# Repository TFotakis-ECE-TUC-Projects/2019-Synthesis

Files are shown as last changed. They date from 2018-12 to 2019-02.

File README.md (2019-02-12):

# TUC Course: Analysis and Design (Synthesis) of Telecommunication Systems
## Project: Distributed Smoke Detection using Lasers

### Development Team Members
Andrianakis Manos
Fotakis Tzanis
Giannakopoulos Orestis
Kotridis Giorgos
Neonakis Paulos
Nichoritis Thanos
Ouroutzoglou Michail
Piskopos Dionisis
Polyzos Christos
Topalis Thanasis

### Professor Assistants
Giannelos Vaggelis
Vougioukas Giorgos

## Supervisor Professor
Bletsas Aggelos

# Introduction
---

## Semester Project Overview
The purpose of this project is to create a wireless sensor network in order to detect smoke in the TUC ECE's department building canteen and pinpoint its source.

### Main idea
Smoke has the ability to diffuse and absorb light, thus, by utilizing cheap sensors such as photodiodes, phototransistors or even photovoltaic panels, the impinging light’s intensity can be tracked and from its waveform in respect to time the existence of smoke can be inferred.
In order to cover a large amount of the available plane, lasers can be used in combination with mirrors as shown in Fig.1. By dividing the plane into cells/tables of 2 rows and 3 columns (see Fig.1), detection of smoke in a specific cell/table can be done by combining data from multiple sensors (e.g., row-1 and column-2 could detect smoke from table-2). 

### Project Structure
Work was split into 3 working groups, Hardware, Middleware and Software, in order to divide the workload among the project members. 
The system includes five sensor nodes (slaves, depicted in Fig.2-right), one base node (master, depicted in Fig.3) and one server PC (laptop, depicted in Fig.4). 
    • Slave: Controls laser diode, measures laser intensity and sends the measurement to the master node.
    • Master: Gives instructions to slave nodes so that they get synchronized to make the laser intensity measurements and to report them back on specific time slots. After the collection of all the measurements, a message to the server is sent with the collected data.
    • Server: Collects measured data, runs the detection algorithm on the collected data and updates the website.

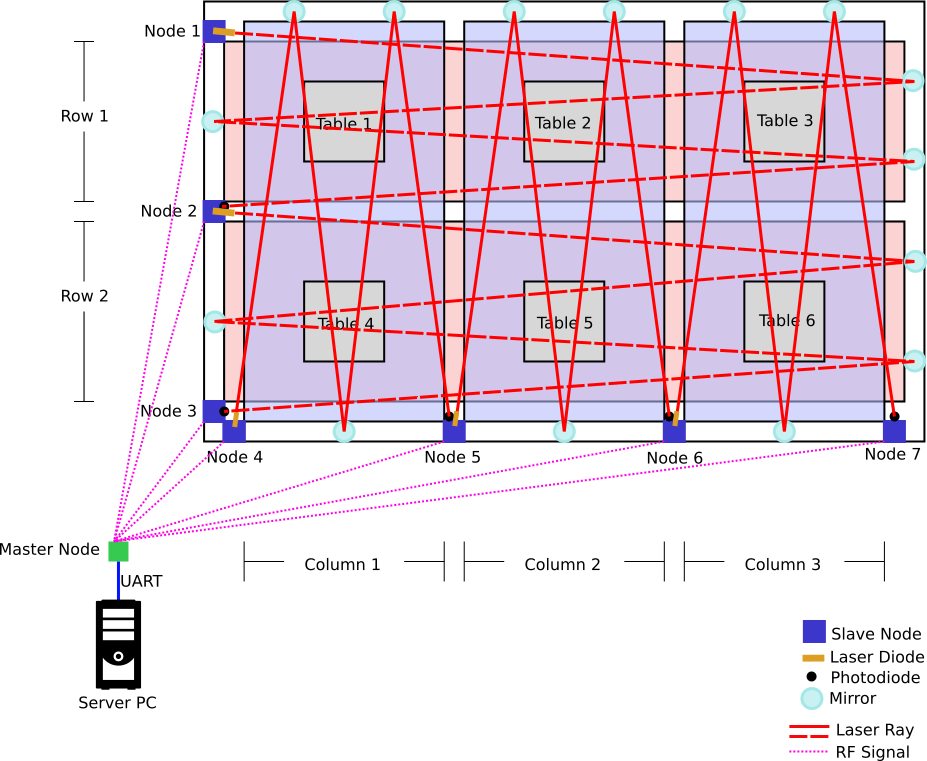
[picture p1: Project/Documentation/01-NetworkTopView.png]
Network Top View

Figure 1: Initial idea. Top view.

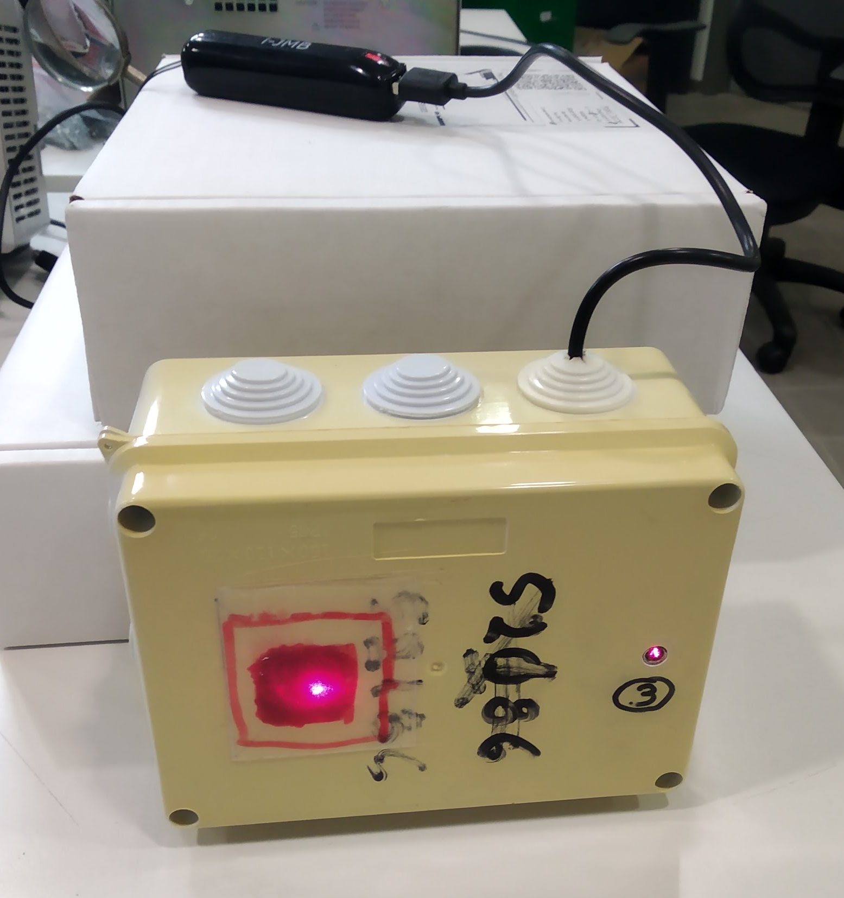
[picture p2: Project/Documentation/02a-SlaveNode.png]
Slave Node

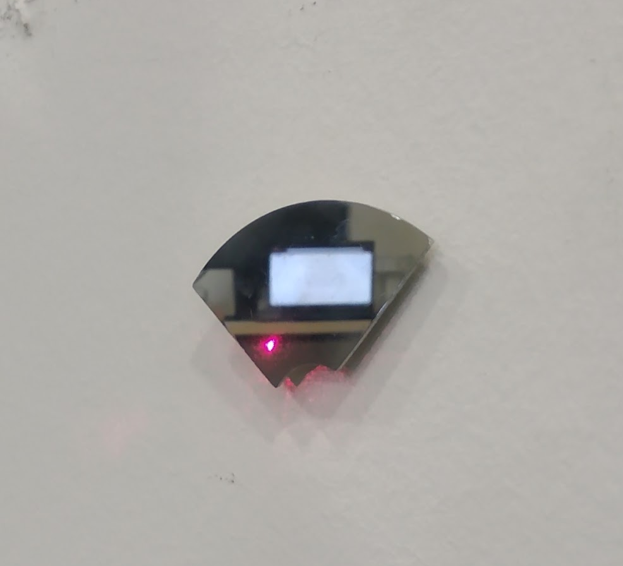
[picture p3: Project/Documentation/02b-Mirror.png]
Mirror

Figure 2: Slave Node on the left, mirror on the right.

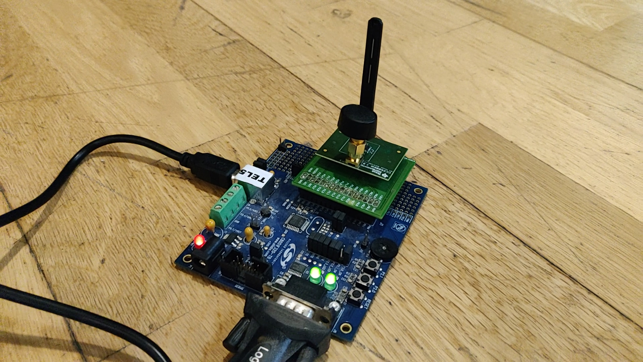
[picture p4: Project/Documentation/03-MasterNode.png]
Master Node

Figure 3: Master Node.

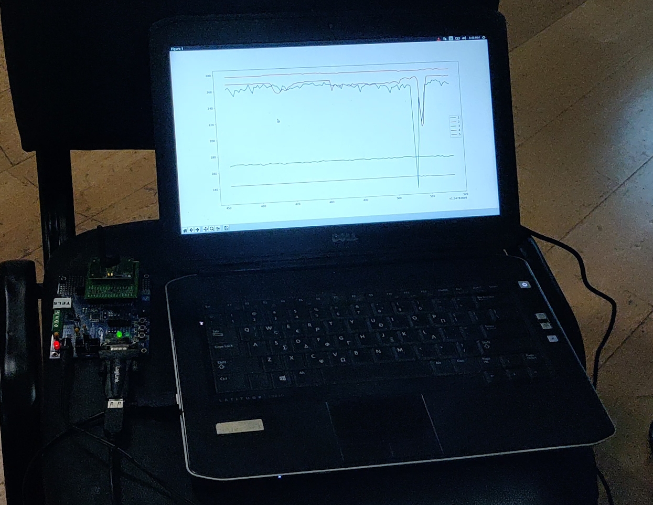
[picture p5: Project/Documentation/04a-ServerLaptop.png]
Server Laptop

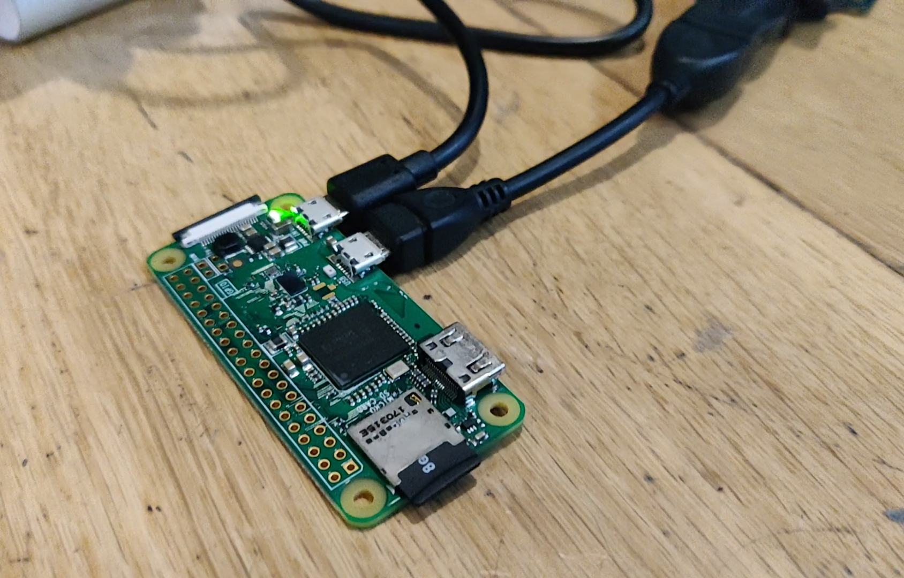
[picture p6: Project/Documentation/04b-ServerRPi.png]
Server RPi

Figure 4: Server on a laptop on the left, Server on a Raspberry Pi Zero W on the right.

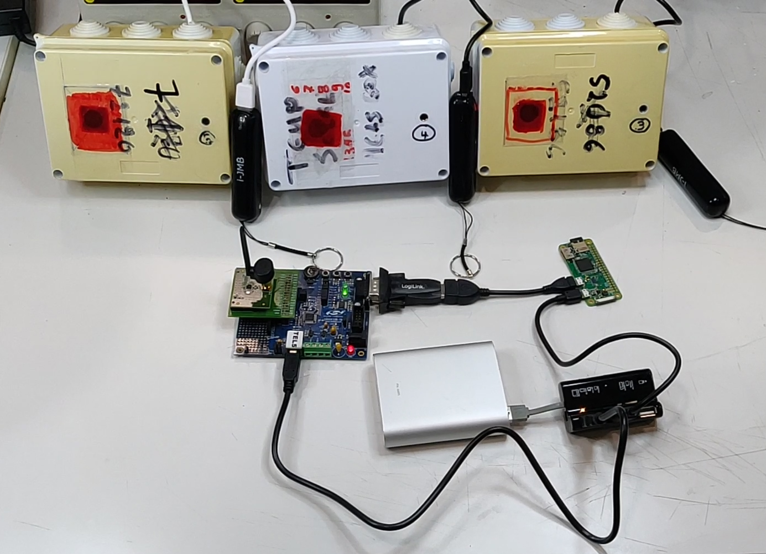
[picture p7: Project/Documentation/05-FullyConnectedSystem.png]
Fully Connected System

Figure 5: Fully connected System.

### Technical Difficulties
Due to environmental difficulties (walls prone to machinery vibrations, mounting issues, etc) that will be discussed below, time limitations became significant to the project’s overall development. As a result, the initial goal of detecting smoke on a grid was transformed into detecting smoke on a serial basis.

# Implementation
---

## Hardware

In this section we shall describe the analog part of our system. 

First of all, we shall analyze the basic hardware, as well as the installation components, that compose the system’s slave nodes.
Components:
    • Diode Laser (red)
    • Photovoltaic Panel
    • Power Supply
    • Mirror reflectors
    • Switching circuit
    • Optical filter
    • Control Unit & Radio
    • Case
    • Mounting Materials

### Diode Laser
For the purpose of our project, Diode Lasers (red) were the most power efficient and low cost. Additionally, red light has the biggest wavelength (compared with green and blue) thus, it is the least harmful for the human eye.

### Photovoltaic Panel
The photovoltaic panel is connected to the ADC (Analog to Digital Converter) of the Daughter Card in order to digitalize the signal.
Power Supply
The power supply was a major and very challenging problem we had to solve. Our first approach was to use conventional batteries. However, this approach did not provide a strictly constant DC voltage as long as the batteries were quickly discharged. So we had to make a regulator circuit to overcome this problem. Instead of this we used power banks, which were low cost, efficient, rechargeable and provided the desired DC constant power supply.
Mirror reflectors
Used to redirect the light beam to the desired destination.

### Switching Circuit

Laser Amplifier Circuit
Figure 6: Laser amplifier circuit.

This circuit was used for duty-cycle purposes, in the interest of minimizing the power consumption of the project. For the implementation of the switching circuit we used the following components:
    • 10 kΩ resistance
    • 2N3904 transistor
The switch circuit is represented in Fig. 6. In order to use the transistor as a switch circuit, we connected a 3,3 V output provided by the used target board via a resistance to the Base of the transistor, while connecting the output of the transistor (Collector) to the negative polarity of the diode laser. As a result, we manage a power consumption approximately to 100 mW for each laser circuit contained in a grid.

### Optical filter
In order to eliminate the ambient light’s intensity inside the slave’s case and only let the laser pass through, optical filters were used. An optical filter is a semi-transparent material that absorbs specific light wavelengths. The ones used in this project were filters that only allowed red pass through, which is the color of the used lasers. Such a filter could be purchased as a sheet of paper. However, for the purposes of this project and because of time shortage, several layers of red colored transparent tape were used in the place of the optical filter. Although, an optical filter cannot cut off the whole ambient light (ambient light also includes red wavelengths) and at the same time let the red laser pass through, it was a good enough solution, cutting off most of the other wavelengths.

### Control Unit & Radio
The slave node’s Control Unit & Radio is comprised of a Silicon Labs C8051F321 Daughter-Card, an 8-bit microcontroller mounted on a small development board with various IO ports (Buttons, IO pins, MicroUSB connector, etc), and a Silicon Labs CC2500 Radio Shield, which is an 8-bit microcontroller with radio modulation capabilities and I2C communication. It is responsible for collecting the needed measurements through its ADC (Analog to Digital Converter) component (see Middleware section), processing them and sending them to the master node and, also, switching its laser’s state for maintaining the system’s low power consumption characteristics.

### Case
Second handed Electrical Junction Boxes were used to accommodate all slave’s components. Two holes were drilled on its front face, one for holding the laser diode and one for letting the laser beam enter the box and hit the photovoltaic panel. The photovoltaic panel was placed as far from the hole as possible in order to eliminate the ambient light hitting it for reasons that will be discussed in the middleware section. For further elimination, the aforementioned optical filter was placed on top of that hole.

### Mounting Materials
Mounting hardware not only inside the slave’s case but also on the walls without establishing permanent installations (e.g. using holes and/or screws) that could damage the building, was a difficult, time and resource consuming task. Solutions such as 3D printed bases were tested in combination with materials such as Blu Tack and double sided tapes. Despite their light weight, stability problems surfaced. Therefore, the lasers' beams were diverted from the target. At last, the slaves cases were mounted on the walls using double sided tape and the reflection mirrors using only Blu Tack, which helped to easily redirect the laser beams.

### Slave Node Overview
Fig. 7 shows the wiring between the components we already discussed. Concerning the power supply of the circuit we used the daughter-card’s pins to provide power for both the circuit and the positive polarity of the laser diode. The daughter-card feeds the laser positive polarity and the switching circuit’s enable signal with VCC = 3.3V. Finally, the daughter-card’s power was provided by a 5V, 2600 mAh power bank which, in paper, could last for more than 18-hours of continuous use.
 
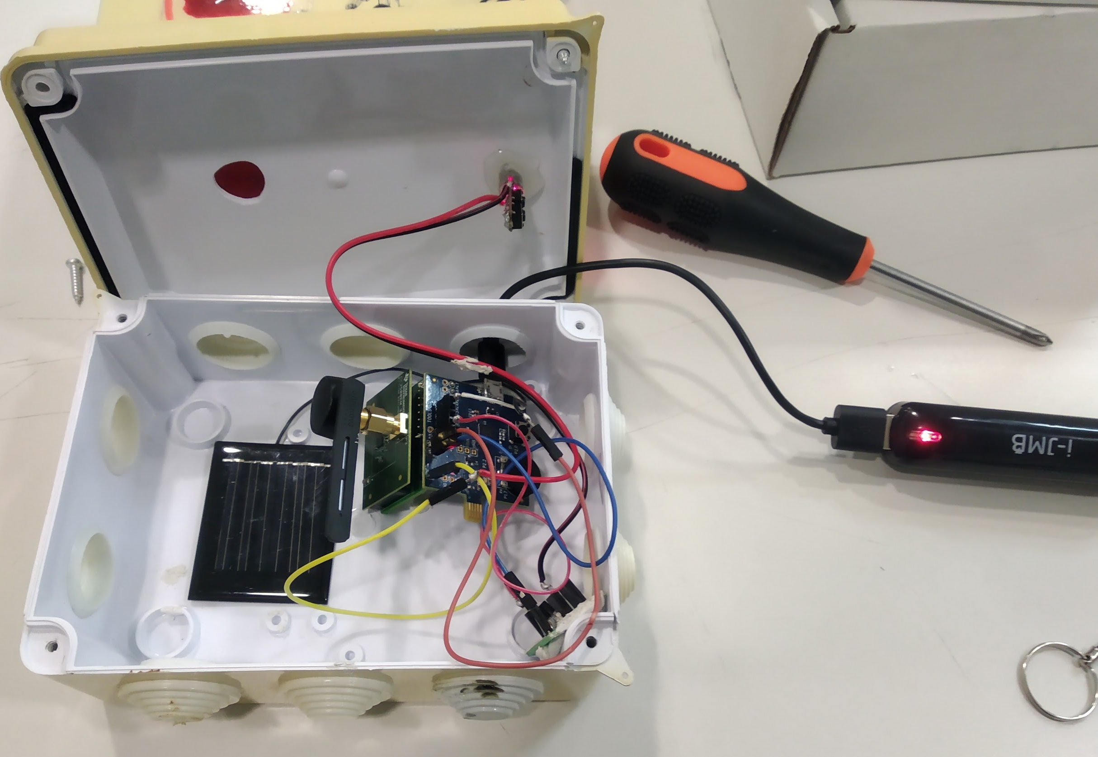
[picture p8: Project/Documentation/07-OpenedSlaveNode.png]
Opened Slave Node

Figure 7: Inside a slave’s casing.

### Master Node Overview
The base station/master node is comprised of a Silicon Labs C8051F320 DevKit, an 8-bit microcontroller mounted on a development board with various IO ports (Buttons, IO pins, DB9 connector, power supply connector, etc), a Silicon Labs CC2500 Radio Shield, an 8-bit microcontroller with radio modulation capabilities and I2C communication, a 5V power adapter and a Serial to USB adapter. The master node exchanges data with all slave nodes via the aforementioned radio shield. The collected data is then forwarded to the server via the DevKit’s serial port (utilizing its UART capabilities), which is then adapted to a USB port through the Serial to USB adapter. The latter is needed because, at the time of writing this report, the serial port is being deprecated and obsolete from every modern PC and also the Laptop/Raspberry Pi was used as a server.

## Middleware

### Connecting The Devices
The main objective was to collect the voltage values from each of the five slaves to the master node in order to forward them to the software to be processed for the detection. Achieving a reliable communication between one slave and the master was the first aim. Afterwards, the master node’s code was adjusted in order to control the rest.
The implementation began by writing code for the exchange of simple packets between the master and the slaves. RF-related registers were fine-tuned with the aid of the smartRF studio 7, which is an application that takes as input the desired design parameters and returns code that configures the nodes’ radios accordingly.
Every device can be used in one of the two available modes, receiver mode and transmitter mode, at a time. Checking for good communication between devices, one was set in transmitter mode and the other in receiver mode. As soon as they exchanged a single packet they would both switch modes and begin a new packet exchange. This process of exchanging packets would continue until a packet was lost. This method is called ping pong because a single packet is sent from one device to another and back again, like a ball of ping pong. 

### Handling the Data
After a reliable communication between devices has been established, the next step was to measure voltage values given from a power supply using the daughter-card’s analog-in pins and converting them into bytes, which will be later sent to the master. For this procedure an ADC (analog to digital converter) is required, an electronic component inside the slave’s microcontroller, which by comparing a port’s voltage to a set reference voltage, returns a measurement from 0 to 1023 of how close the port’s voltage is to the reference’s voltage. This method is called analog to digital conversion, because it accepts an analog, continuous signal and converts it into a discrete number referring to a specific moment of time. Following the addition of the appropriate functionality for the ADC part, the results of the converter were put in the tx Buffer (the buffer where the values that we want to be sent are into) in order to be transmitted to the master. After receiving the values from the slave, it was needed to view if the values from the power supply were sent correctly and in order to the master. Functionality extension had be made on the master, so that serial port communication capabilities could be used via the UART protocol. In order to view the received data from the PC, the Hercules application was used.

### Communication protocol
According to the initial plan, the master node was supposed to send a request to the first slave, waiting to receive a measurement, and then proceed to the next. After the implementation of this protocol, we came to the conclusion that this was not the ideal method as the whole procedure took around 2.5 seconds (500ms for each slave). This period was way too big for a smoke detection task, so a new, faster protocol had to be designed.
The final communication protocol expects the master to broadcast to all slaves an instruction to take a measurement. After the needed period of time for a measurement to be made (approximately 200ms), the master, starting from the first slave, sends a packet to request for that measurement and when received it continues to the next one, until it has collected all slaves’ measurements. That method was proved to be fast enough for our implementation as the elapsed time is being reduced to around 500ms.
Although, another issue occurred, as in unpredicted time, the communication ended suddenly, because a transmitted packet was lost. In this case, the procedure crashed as the master waited forever for a packet to be received. For that reason, a timeout routine was created which leads to a timeout after a short, pre defined period of time of 100ms, in order to avoid system crashes. When a timeout occurs, master continues its execution and requests the next node’s measurement. As a result, even in the case that a slave node is being lost from the network (e.g. battery fully discharged, change in environment leading to poor network connection, etc), the system’s execution will continue with no impact, except for always sending the last received measurement of the lost node.

### Measurements
To get a sense of the photovoltaic’s behaviour under the ambient light and the selected laser beam, measurements were made using one of the lab’s oscilloscope. Because most of the ambient light was generated from fluorescent lamps, which their operating principle is charging mercury to emit ultraviolet light to the tube’s gas, which it then emits visible light, a frequency of around 100 Hz was detected. Trying to remove that frequency, as well as, the ADC’s measurement noise, an average of 2048 measurements was computed, which was then sent to the master.
As soon as the first real world test took place at the desired area revealing the realistic measurements that had to be taken under consideration, a slight change in the measurement’s functionality had to be made in order to increase the sensitivity. The previous measurement method disadvantage was that it only measured ambient light’s intensity (which cannot be avoided) in combination with the laser’s intensity. However, the wanted measurement was (if possible) to measure only the laser’s intensity. So, to eliminate the ambient light’s intensity, it had to be measured and subtracted from the combination of ambient light and laser. The final measurement method works as follows: 
The laser is turned on, while the ADC takes 1024 measurements which are summed up to a variable, SUM, representing a measurement of the combination of the ambient light and the laser. Afterwards, the laser is turned off, while the ADC takes another 1024 measurements, which represent a measurement of the current ambient light. Those measurements are then subtracted from the SUM variable. Finally, the SUM is divided by 1024 to calculate the measurements’ arithmetic mean, which represent a close approximation of the laser’s intensity. To further eliminate ambient light’s intensity which caused the photovoltaic to operate on its nonlinear area, an optical filter, which only lets red (the laser’s color) to pass through, was used as discussed above.

### Master Node Algorithm Flow Chart
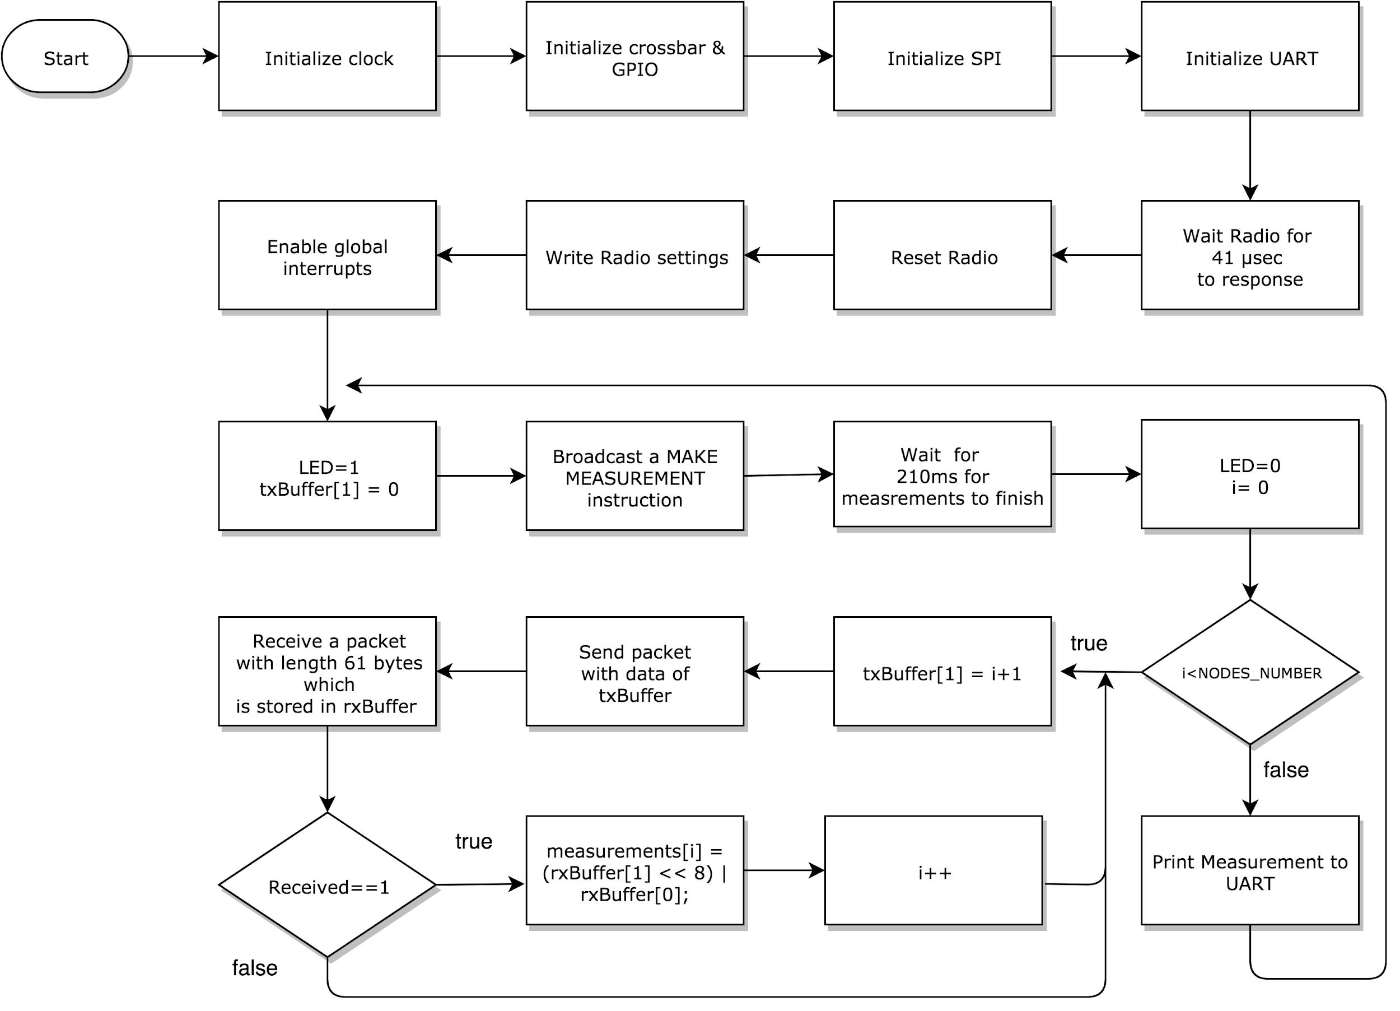
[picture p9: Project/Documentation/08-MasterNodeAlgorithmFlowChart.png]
Master Node Algorithm Flow Chart

Figure 8

### Slave Node Algorithm Flow Chart
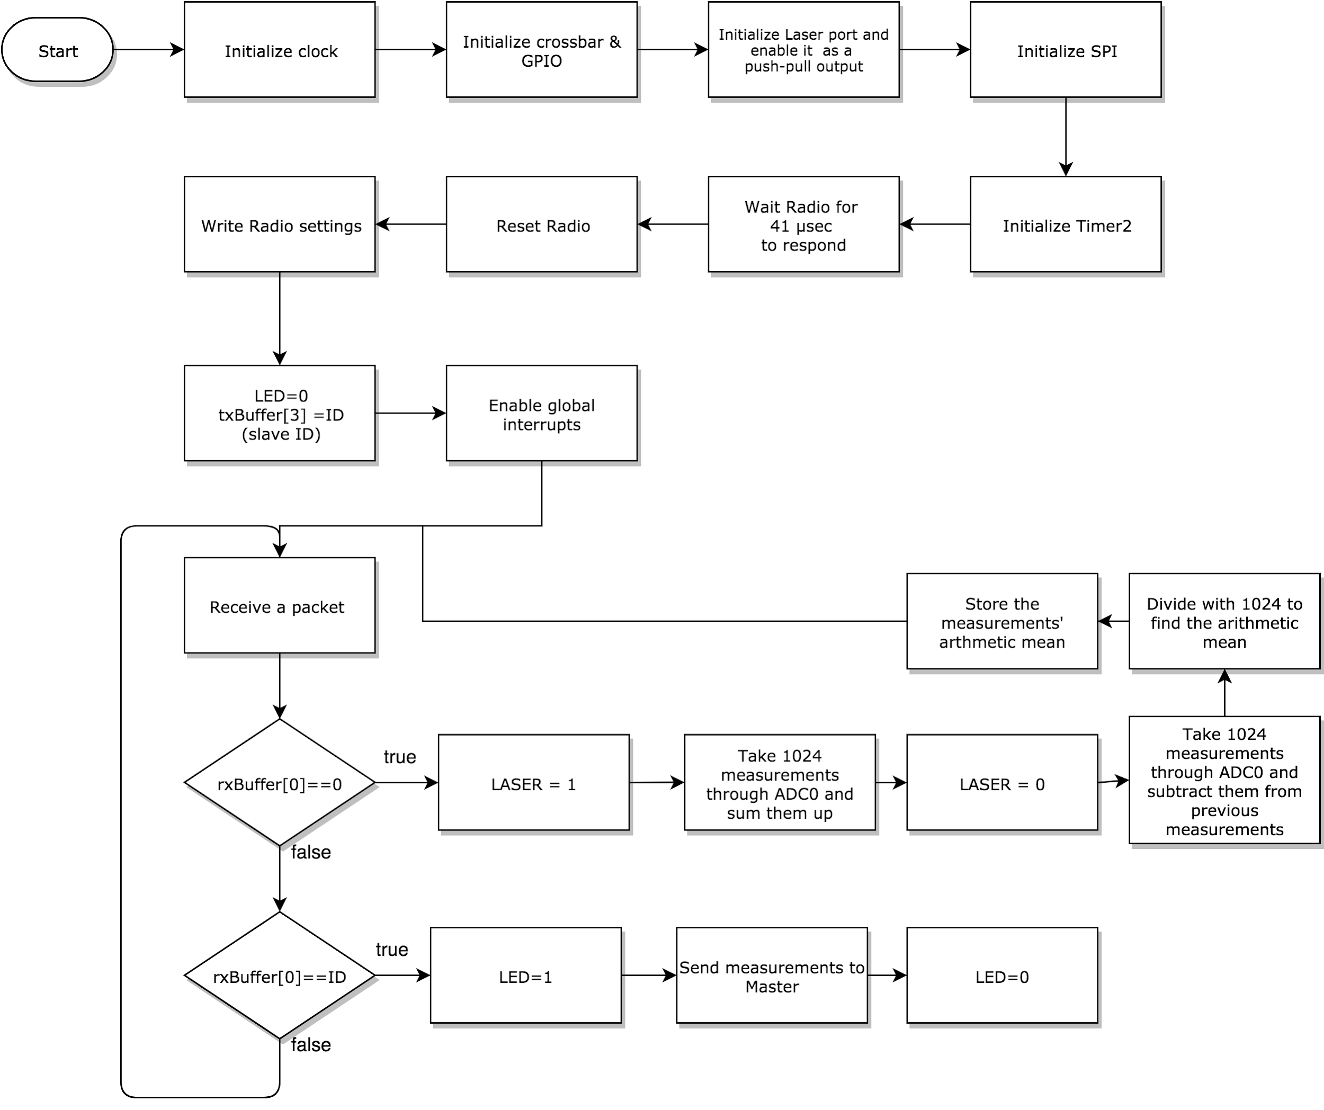
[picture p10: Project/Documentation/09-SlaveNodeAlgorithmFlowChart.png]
Slave Node Algorithm Flow Chart

Figure 9

## Software
The software team was responsible for fetching the data from the master node, keeping a log of them, and plotting them on MATLAB-like environment for the user to overwatch. In addition to that, accurate real-time detection of smoke is offered through simple digital signal processing, as well as the ability to project this information on a website, reachable from throughout the campus, alongside (un)pleasant sound effects as a notification/warning for the end user.

### Website & Data Handling
The website’s backend was created using the DJango framework, a high level web framework for rapid development, clean and pragmatic design. As it uses Python, it was the most suitable for the project’s needs because the smoke detection algorithm could be easily implemented inside the backend’s features. Last but not least, the data collection from the master node is done using the UART protocol through the PC’s serial port. 
On server launch, a new thread is created with the purpose of reading the serial port and storing its data into a FIFO buffer, from which the detection algorithm could make the needed calculations. Whenever a new calculation is ready, it is stored in a variable which can be sent to all the website’s connected clients. This thread also logs the received data, the timestamp of each measurement and the result of the detection. This can be quite useful since it allows the user to examine events in the past, even if the system is left unsupervised.
Another thread is also spawned in order to plot the received waveforms of each sensor on the screen.
The reason why separate threads are needed is because some of the aforementioned functionalities are blocking, meaning that the server would not continue its execution if single threaded.
The website’s frontend was created using plain HTML5 and CSS3 for the user interface as well as jQuery for dynamically updating the states of the predefined measured areas. In more detail, when the website is accessed, a periodic routine is triggered every 8 second to request from the server the current areas’ states. A json response is returned from the backend containing the needed data, which are stored in the previously mentioned variable. 
Whenever smoke is detected in an area, the corresponding area on the website turns from green to red and a sound effect is played, in order to catch the attention of the users.

### Observations On Data
Several factors were considered before deciding what is a good way to approach the detection. 
The ambient light introduced bias on the sensors. Normally this wouldn’t pose a problem, however considering the day/night cycle as well as the lights turning on/off, this was a problem. In addition to that, if the smoke settled in the room, the ambient light as well as the laser rays would be affected by a slow, time-dependant factor (e.g., day/night transition, smoke clearing out). These effects are different on each sensor considering their different location in the room and their electronic characteristics (e.g., panels are physically very different from each other).
The above observations are proof that the detection method needs to be able to adjust on its own, for each sensor, to a slow changing environment.
In contrast to the previous, instability on the part of the mirrors, due to vibrations etc., coupled with the thermal noise of the ADC, flickering can be noticed on the measurements. This small fluctuation needs to be filtered out and not be considered in the detection as it can potentially cause false positives.
Thus, it is now clear that the constant (or very slow), and fast components of the received waveforms must be discarded.

### DSP & Detection
Having said that, the digital signal processing part is now a lot more straightforward. By performing Discrete Time Fourier Transform (DTFT) on small time frames of the received waveforms, frequencies (such as the above) can be cropped in order to detect smoke from the rest of the signal. When there is no smoke, the intermediate frequencies (higher than 0 less than 1, see Fig. 11 left) offer small contribution to the overall signal. However, when smoke passes through the laser ray, a sudden drop at the sensor level occurs (also see in Fig. 11 right, how the intermediate frequencies get significant amplitude). A heuristic metric was developed by calculating the arithmetic mean of the absolute value of the intermediate frequencies. Through trial and error, a heuristic threshold value was identified and used as a means of checking whether there is smoke or not. Surprisingly, this method works quite good, all things considered.

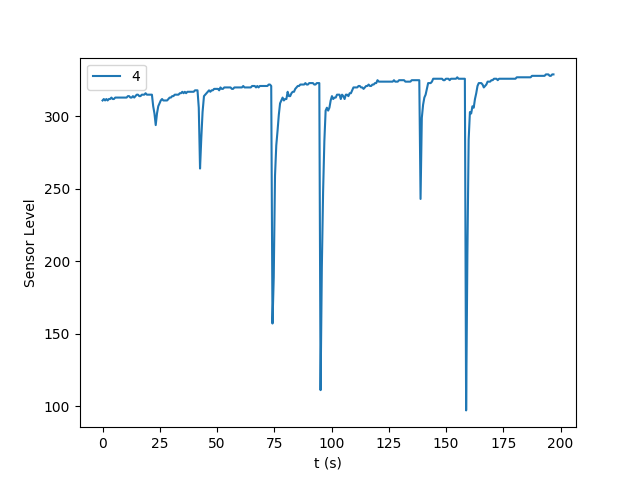
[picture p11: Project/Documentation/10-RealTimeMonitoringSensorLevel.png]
Real Time Monitoring Sensor Level

Figure 10: Real-time monitoring of Sensor Level.

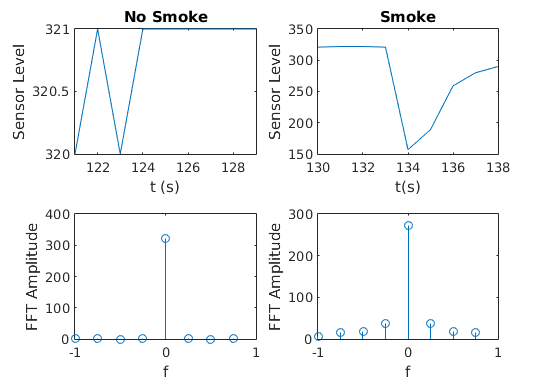
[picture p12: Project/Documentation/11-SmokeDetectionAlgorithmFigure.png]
Smoke Detection Algorithm Figure

Figure 11: The top figures are time windows without and with smoke. The bottom figures are their corresponding FFT waveforms. 

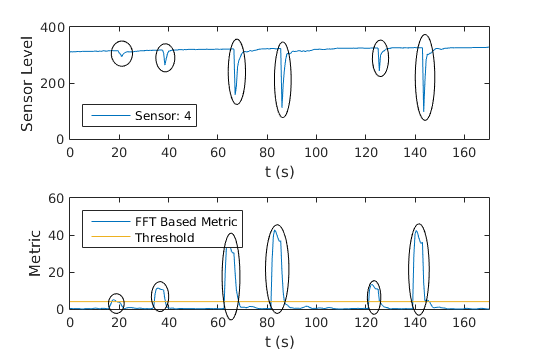
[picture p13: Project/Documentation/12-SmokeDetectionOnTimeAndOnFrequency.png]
Smoke Detection On Time And On Frequency

Figure 12: Waveform of sensor level (top), alongside the FFT based metric compared to the heuristic threshold (bottom). 

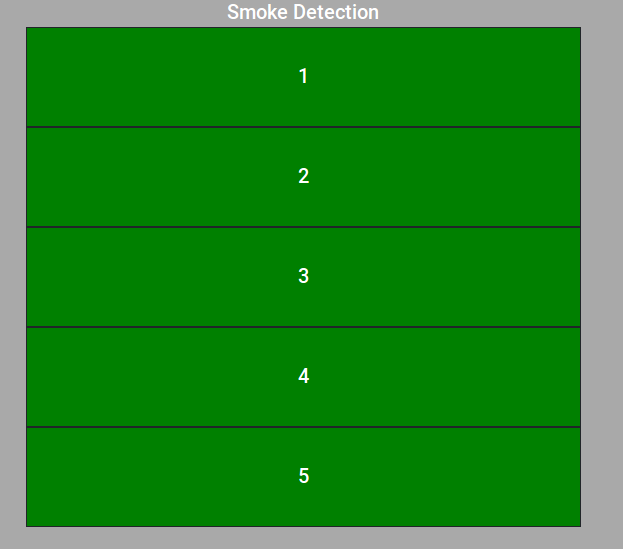
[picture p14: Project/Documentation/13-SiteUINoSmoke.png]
Site UI No Smoke

Figure 13: Website view without smoke.

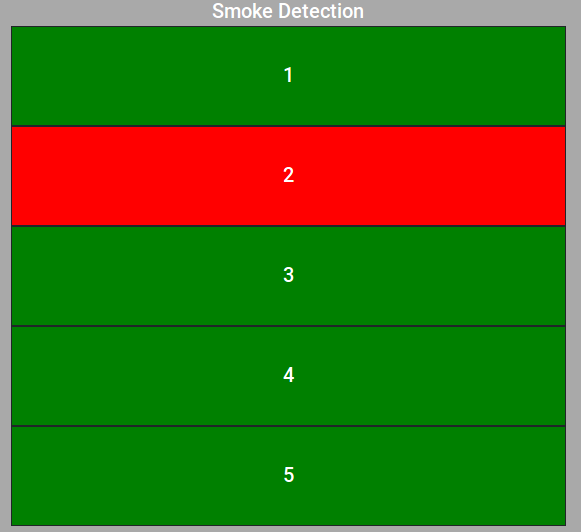
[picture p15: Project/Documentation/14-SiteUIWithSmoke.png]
Site UI With Smoke

Figure 14: Website view with smoke.

# Future Work
---
## Hardware
Low cost laser modules come with low quality, poor focus performance and endurance. In addition, generic mirrors affects laser beams’ focus and intensity over multiple reflections. Overall, the received beam on the photovoltaic panel loses its property of being a “beam” as it is getting distorted after all the needed reflections and its initial low focus. Optimizing the laser’s wavelength by selecting the one that gets the greatest absorption from gases that need to be detected, even other than smoke or even invisible to the human eye such as CO or dangerous flammable gases. Furthermore, optimized optical filters, better mounting solutions and smaller casing could improve sensitivity and ease of installation. 

## Middleware
Power consumption can be reduced using the minimum required  power output of transmitter in order to meet the requirements of  sensitivity of receiver for a successful communication. Also, lower data rate could lead to power efficiency.

## Software
Due to time constraints, the detection had to be performed in a simple straightforward way. The result is that we came up with a heuristic metric and a heuristic threshold that may require fine-tuning overtime. In the future, neural networks could be facilitated in order to make the system smarter and enabling it to pinpoint the exact location of the smoke, by comparing values of multiple (with possibly intersecting rays) sensors. Another benefit of this approach would be that we can drop the heuristic metrics and thresholds, thus making the detector much more robust and independent (in terms of fine-tuning).

# Links
---
Youtube Demo Video: https://youtu.be/7rDN7ZuSLMw
GitHub Repository: https://github.com/TFotakis/TUC-Synthesis

# The Team
---
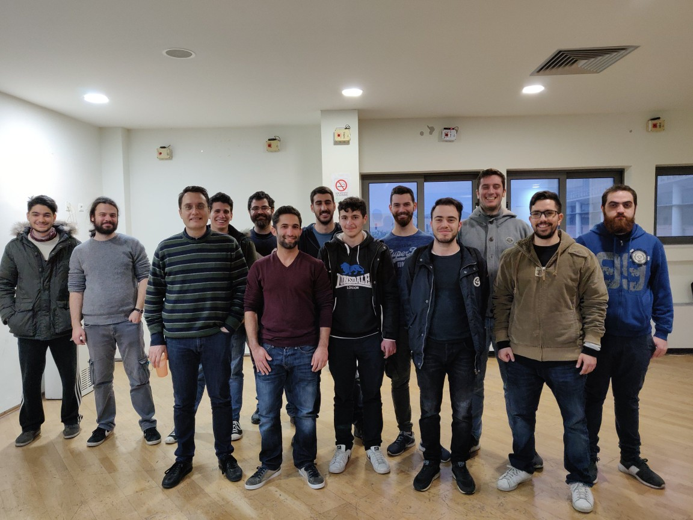
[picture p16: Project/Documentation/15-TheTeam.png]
The Team


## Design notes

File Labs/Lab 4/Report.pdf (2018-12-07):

# Ανάλυση και Σχεδίαση Τηλεπικοινωνιακών Διατάξεων

### Αναφορά Εργαστηρίου 4 Φωτάκης Τζανής - 2014030054

Σε συνεργασία με Πίσκοπο Διονύση

## Βρείτε τον ρυθμό bits per second (bps) του ADC και τον ρυθμό

bps του UART. Χάνονται δεδομένα? Εξηγήστε συνοπτικά.

Εξετάζοντας τον δοσμένο κώδικα, γίνονται αποδεκτά τα παρακάτω:
- Το UART είναι ρυθμισμένο σε 115200 Baudrate, δηλαδή έχει την ικανότητα να μεταδίδει από τον μικροελεγκτή προς την σειριακή θύρα με ρυθμό RATEUART=115200 bits per second των οποίων μέρος είναι η χρήσιμη πληροφορία (μέτρηση ADC) και ένα άλλο μέρος είναι πληροφορία του πακεταρίσματος του μηνύματος.
- Ο ADC ξεκινάει ένα conversion κάθε 100μs που σημαίνει ότι κάθε 100μs δίνεται στο σύστημα ένα interrupt για το γεγονός ότι υπάρχει μία έτοιμη τιμή από τον ADC.
- Δημιουργείται ένας μέσος όρος των μετρήσεων του ADC με πλήθος 2048 μετρήσεις και αμέσως μετά το αποτέλεσμα του μέσου όρου αποστέλλεται στο UART.
- Ο ADC δίδει ακρίβεια 10bit, δηλαδή μπορεί να αναγνωρίσει 1024 διαφορετικές στάθμες τάσης, άρα θα πρέπει να μεταδοθεί μήνυμα 10bit μέσω του UART.
Σύμφωνα με τα παραπάνω προκύπτει ότι:
RATE | 8.82 bits per second ADC =

10bit
2048 conversions * 100 10 sec

−6 = 4

Άρα επειδή RATEADC << RATEUART μπορούμε να είμαστε σίγουροι ότι δεν χάνονται δεδομένα από τον ADC προς την σειριακή θύρα.

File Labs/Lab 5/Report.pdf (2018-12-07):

# Ανάλυση και Σχεδίαση Τηλεπικοινωνιακών Διατάξεων

Αναφορά Εργαστηρίου 5
Πίσκοπος Διονύσης - 2015030115 Φωτάκης Τζανής - 2014030054

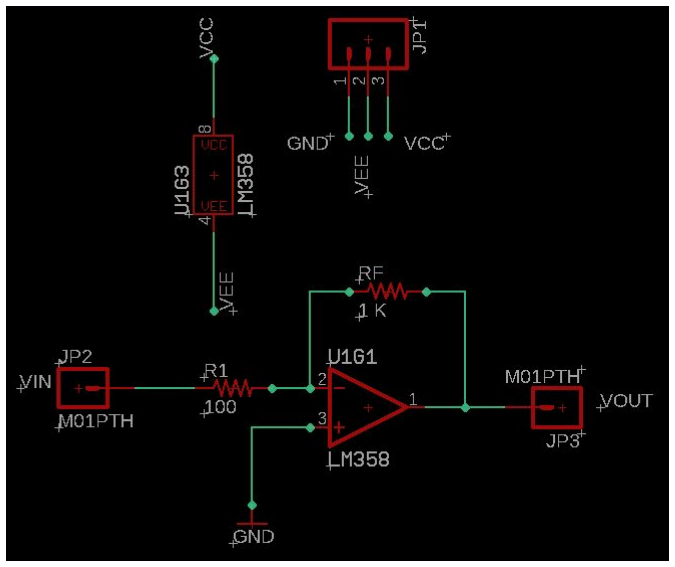
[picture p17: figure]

OpAmp Schematic

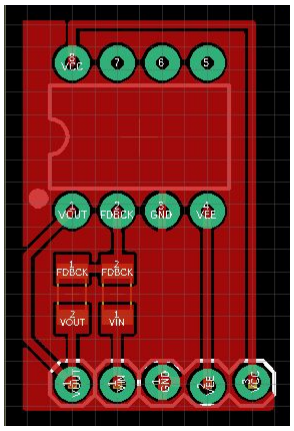
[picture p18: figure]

OpAmp Layout

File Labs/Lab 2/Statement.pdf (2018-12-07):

Πολυτεχνείο Κρήτης
Τμήμα Ηλεκτρονικών Μηχ\κών & Μηχ\κών Η\Υ

### Χειμερινό Εξάμηνο 2010-2011

# ΤΗΛ 412 Ανάλυση και Σχεδίαση (Σύνθεση)

## Τηλεπικοινωνιακών Διατάξεων

7

ου Εξαμήνου

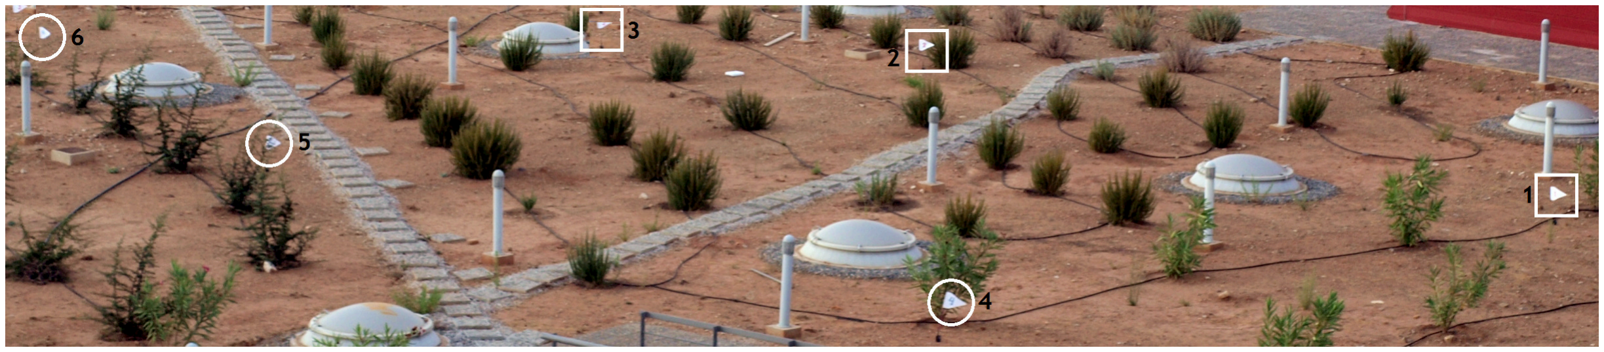
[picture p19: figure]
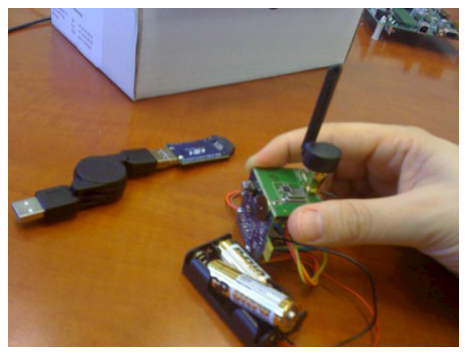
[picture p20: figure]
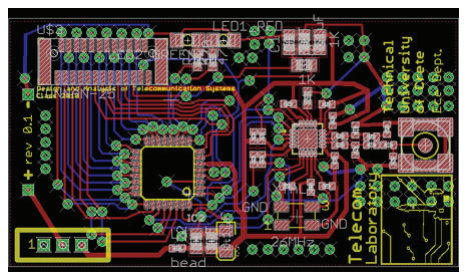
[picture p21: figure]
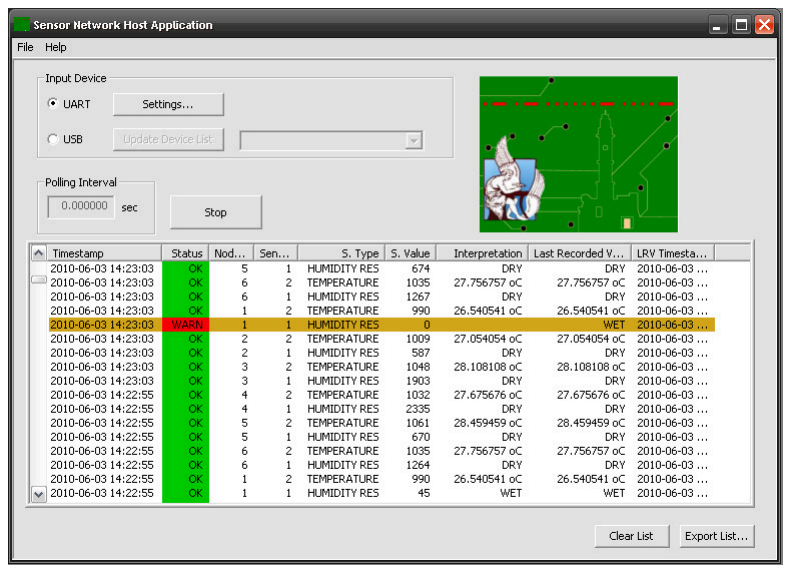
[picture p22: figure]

## Σειριακή Επικοινωνία Υπολογιστή με Πλακέτα

## Ανάπτυξης

Υποστηρικτικό Υλικό
Διδάσκων: ΄Αγγελος Μπλέτσας aggelos@telecom.tuc.gr

### version 0.1.0

1 | Εισαγωγή
1.1 | Σειριακή Διεπαφή (J5)

Η πλακέτα ανάπτυξης C8051F320 που χρησιμοποιείται στα πλαίσια του εργαστηρίου του μαθήματος, είναι εξοπλισμένη με ένα RS-232 κύκλωμα πομποδέκτη καθώς και ένα DB-9 connector.
Τα παραπάνω μπορούν να χρησιμοποιηθούν, με σκοπό την καλύτερη αποσφαλμάτωση και τον έλεγχο ορθής λειτουργίας των συστημάτων που υλοποιούμε μέσω της εκτύπωσης στην οθόνη μηνυμάτων ή τιμών μεταβλητών.
Για χάριν της καλύτερης εξοικείωσης σας με την δημιουργία σειριακής επικοινωνίας μεταξύ του υπολογιστή και της πλακέτας ανάπτυξης σας δίνεται το project με όνομα UART EXAMPLE το οποίο βρίσκεται στον φάκελο με τον κωδικό του μαθήματος στον υπολογιστή του κάθε πάγκου του εργαστηρίου. Για την επεξεργασία του κώδικα θα χρησιμοποιηθεί η πλατφόρμα της Sillabs Επιπλέον σας δίνεται το header file C8051F320.h που περιέχει ορισμούς σταθερών παραμέτρων του μικροελεγκτή μας.
Για την επεξεργασία των κωδίκων και την φόρτωση τους στον μικροελεγκτή θα χρησιμοποιηθεί η πλατφόρμα της Silabs ενώ σαν τερματικό θα χρησιμοποιηθεί το Hercules, μία standalone εφαρμογή, το εκτελέσιμο αρχείο της οποίας είναι επίσης τοποθετημένο στον φάκελο με τον κωδικό του μαθήματος.

2 | Εφαρμογή Hercules
2.1 | Εγκατάσταση και Λειτουργία

΄Οπως αναφέραμε παραπάνω το εκτελέσιμο αρχείο της εφαρμογής Hercules είναι τοποθετημένο στον φάκελο με όνομα τον κωδικό του μαθήματος.
Αφότου εκκινήσετε την εφαρμογή, θα σας εμφανιστεί ένα παράθυρο όπως αυτό απεικονίζεται στο Σχήμα 1.

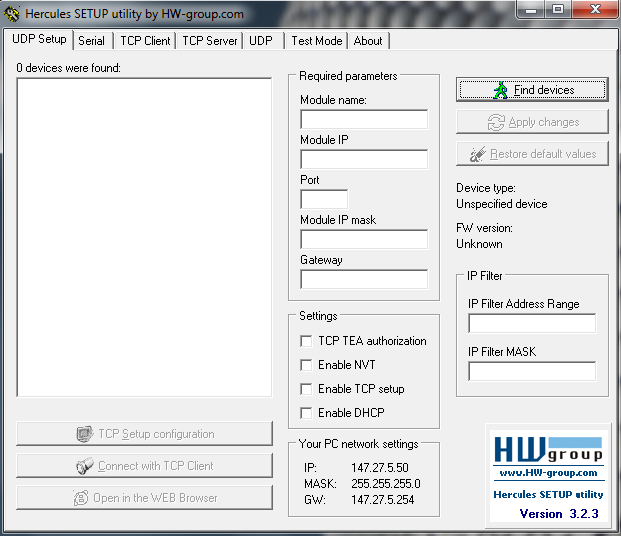
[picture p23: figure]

Σχήμα 1: Εκκίνηση τερματικού παραθύρου της εφαρμογής Hercules.

Στην συνέχεια επιλέγοντας την καρτέλα Serial καλείστε να ρυθμίσετε κάποιες παραμέτρους στο δεξί μέρος του παραθύρου, όπως αυτό της σειριακής θύρας (π.χ. COM1 ).

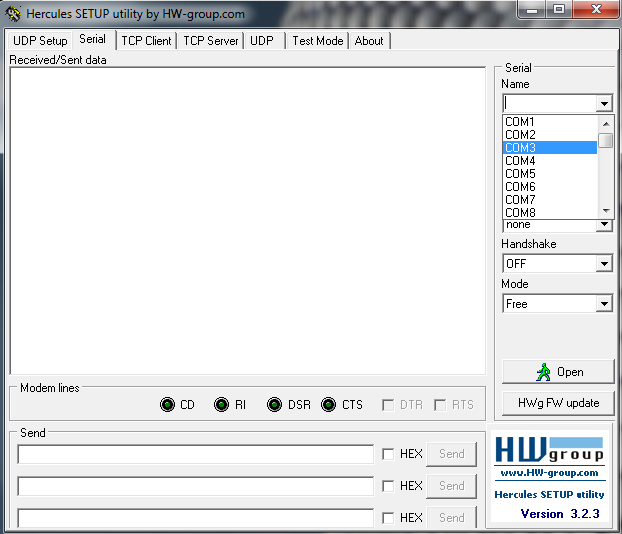
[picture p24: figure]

Σχήμα 2: Εφαρμογή Hercules (συνέχεια).

΄Ετσι για την ορθή ρύθμιση των παραμέτρων, χρειάζεται αφού πρώτα συνδέσετε τον Serial to USB μετατροπέα στην αντίστοιχη θύρα, να μεταβείτε στον Device Manager του υπολογιστή σας. Στην καρτέλα για τις σειριακές θύρες (Ports (COM & LPT)) αφού δείτε τον αριθμό της εικονικής σειρι-

ακής θύρας που δημιουργήθηκε, τον επιλέγετε στην αντίστοιχη καρτέλα της εφαρμογής Hercules.

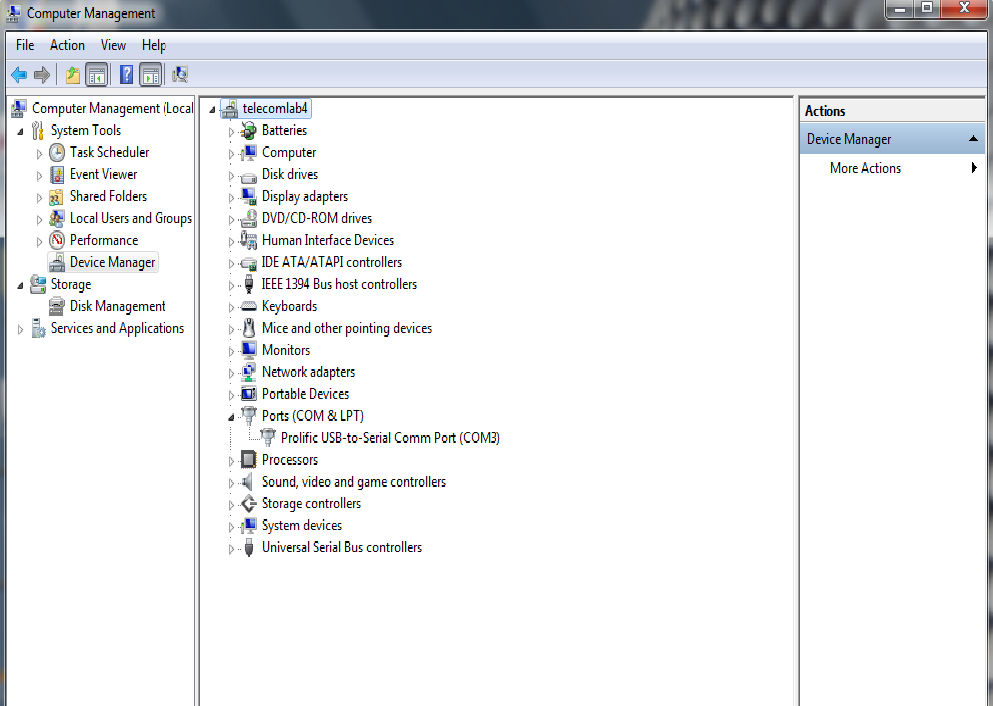
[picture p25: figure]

Σχήμα 3: Ρύθμιση παραμέτρων στην εφαρμογή Hercules.

΄Επειτα, σας δίνεται η δυνατότητα να επιλέξετε διαφορετική τιμή για το Baud Rate κάτι το οποίο δεν πρέπει να ξεχάσετε να δηλώσετε σαν σταθερά στον κώδικα σας. Η default τιμή του είναι 9600 και είναι αυτή που χρησιμοποιείται στο παράδειγμα το οποίο θα εξασκηθείτε.
Τέλος με το κουμπί open η σειριακή θύρα θα ‘ανοίξει’ και θα είναι έτοιμη για την λήψη δεδομένων από την πλακέτα ανάπτυξης.

## 3 Περιγραφή Δοθέντος Λογισμικού

Στο παράδειγμα που σας δίνεται, μπορείτε να εισάγετε κάποιο χαρακτήρα και το τερματικό θα εκτυπώσει την είσοδο σας από το πληκτρολόγιο σε δεκαεξαδική μορφή.
΄Ενα παράδειγμα υλοποιήσης εμφανίζεται στο Σχήμα 4.

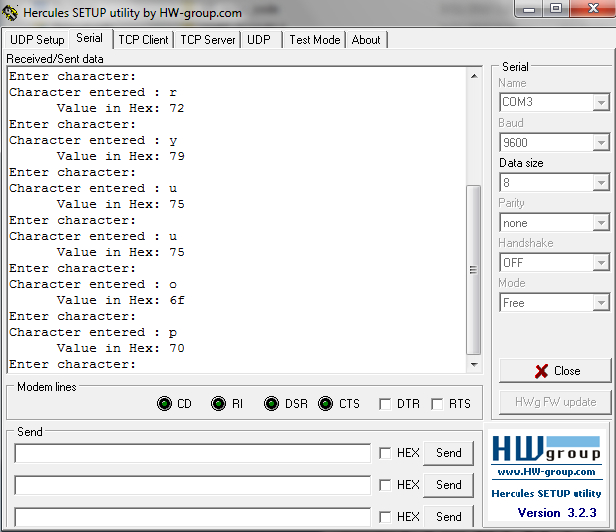
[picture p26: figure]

Σχήμα 4: Παράδειγμα F32x UART STDIO.c στην εφαρμογή Hercules.

## 3.1 Κώδικας F32x UART STDIO.c

Ορισμός των header files που περιέχουν απαραίτητες δηλώσεις καταχωρητών καθώς και συναρτήσεων απαραίτητων για διάβασμα από το πληκτρολόγιο και εκτύπωση στην οθόνη.

#include <c8051f320.h> | // SFR declarations

#include <stdio.h>

#include <common.h>

Στην συνέχεια ορίζονται 2 σταθερές όπως η συχνότητα του εσωτερικού ταλαντωτή η οποία τίθεται στα 12MHz ενώ ο ρυθμός μεταφοράς δεδομένων στην σειριακή επικοινωνία ορίζεται στα
9600bps.
#define SYSCLK | 12000000 | // SYSCLK frequency in Hz

#define BAUDRATE | 9600 | // Baud rate of UART in bps

Ακόμη ορίζεται ένας buffer με το όνομα myData τύπου BYTE ο οποίος θα αποθηκευτεί σ΄ ένα άλλο κομμάτι της μνήμης (xdata) για το οποίο έχει γίνει εκτενής περιγραφή στην αναφορά

του προηγούμενου εργαστηρίου.

BYTE xdata myData[]= {20, 0, 1, 2, 3, 4, 5, 6, 7, 8, 9, 10, 11, 12, 13, 14};

Ορισμός των πρωτοτύπων των συναρτήσεων που μερικές από τις οποίες θα χρησιμοποιηθούν
στο παρακάτω πρόγραμμα (UART0 Init, SYSCLK Init, PORT Init).

void SYSCLK_Init (void);
void UART0_Init (void);
void PORT_Init (void);
void Timer2_Init (int);

Στην κύρια συνάρτηση του προγράμματος μας αφού πρώτα ορίσουμε μια μεταβλητή τύπου χαρακτήρα, απενεργοποιήσουμε τον watchdog timer και καλέσουμε τις 3 απαραίτητες συναρτήσεις για την αρχικοποίηση των Ports, του εσωτερικού ταλαντωτή και της σειριακής επικοινωνίας αντίστοιχα, καλούμε την συνάρτηση printf με ορίσματα τις προτάσεις που θέλουν να εκτυπωθούν στην οθόνη. Να επισημάνουμε ακόμη ότι η συνάρτηση getChar() χρησιμοποιείται για το διάβασμα

χαρακτήρων από το πληκτρολόγιο.

void main (void)
{
unsigned char inputcharacter;
int byteAsInt;
int iter;
PCA0MD &= ~0x40; | // WDTE = 0 (clear watchdog timer
| // enable)
PORT_Init(); | // Initialize Port I/O
SYSCLK_Init (); | // Initialize Oscillator
UART0_Init();
while (1)
{
printf ("\nEnter character: ");
inputcharacter = getkey ();
printf("\nCharacter entered : %c",inputcharacter);
printf("\n | Value in Hex: %bx",inputcharacter);
printf("\n");
printf("Buffer myData:");
for (iter=1;iter<=(sizeof(myData)-1);iter++){ byteAsInt=myData[iter];
printf("%d ",byteAsInt);
}//end of for
printf("\n");
}
}

΄Ετσι καλούμαστε να εισάγουμε σαν είσοδο κάποιο χαρακτήρα και το πρόγραμμα μας θα εκτυπώσει την τιμή του χαρακτήρα σε δεκαεξαδική μορφή.

Επιπροσθέτως, ένας βρόγχος επανάληψης for υλοποιείται, με σκοπό την εκτύπωση στο τερματικό των στοιχείων του buffer που ορίστηκε παραπάνω.
Παρακάτω ακολουθούν οι κώδικες των συναρτήσεων που καλούνται κατά την διάρκεια του προγράμματος.
Αρχικά με την κλήση της PORT Init θα ενεργοποιήσουμε το P0.4 ως push-pull ψηφιακή έξοδο
και το P0.5 ως open-drain.

void PORT_Init (void)
{
P0MDOUT |= 0x10; | // enable UTX as push-pull output
XBR0 | = 0x01; | // Enable UART on P0.4(TX) and P0.5(RX)
XBR1 | = 0x40; | // Enable crossbar and weak pull-ups
}

Την συνάρτηση SYSCLK Init την έχετε επίσης συναντήσει σε προηγούμενα εργαστήρια και χρησιμοποιείται για να καθορίσουμε ως ρολόι του συστήματος τον εσωτερικό ταλαντωτή.

void SYSCLK_Init (void)
{
OSCICN |= 0x03; | // Configure internal oscillator for
// its maximum frequency
CLKSEL = 0x20;
RSTSRC | = 0x04; | // Enable missing clock detector

}

Τέλος η συνάρτηση UART0 Init χρησιμοποιείται για την εγκαθίδρυση σειριακής επικοινωνίας ανάμεσα στον υπολογιστή και στην πλακέτα ανάπτυξης με ρυθμό μεταφοράς που ορίζεται στις πρώτες γραμμές του προγράμματος.

void UART0_Init (void)
{
SCON0 = 0x10; | // SCON0: 8-bit variable bit rate
// | level of STOP bit is ignored
// | RX enabled
// | ninth bits are zeros
// | clear RI0 and TI0 bits
if (SYSCLK/BAUDRATE/2/256 < 1) {
TH1 = -(SYSCLK/BAUDRATE/2);
CKCON &= ~0x0B; | // T1M = 1; SCA1:0 = xx
CKCON |= | 0x08;
} else if (SYSCLK/BAUDRATE/2/256 < 4) {
TH1 = -(SYSCLK/BAUDRATE/2/4);
CKCON &= ~0x0B; | // T1M = 0; SCA1:0 = 01
CKCON |= | 0x01;

} else if (SYSCLK/BAUDRATE/2/256 < 12) {
TH1 = -(SYSCLK/BAUDRATE/2/12);
CKCON &= ~0x0B; | // T1M = 0; SCA1:0 = 00
} else {
TH1 = -(SYSCLK/BAUDRATE/2/48);
CKCON &= ~0x0B; | // T1M = 0; SCA1:0 = 10
CKCON |= | 0x02;
}
TL1 = TH1; | // init Timer1
TMOD &= ~0xf0; | // TMOD: timer 1 in 8-bit autoreload
TMOD |= | 0x20;
TR1 = 1; | // START Timer1
TI0 = 1; | // Indicate TX0 ready
}

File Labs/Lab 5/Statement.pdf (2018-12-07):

Technical Universtiy of Crete
E.C.E Department
Fall Semester 2010-2011

## TEL 412 Analysis and Design (Synthesis) of Telecom Modules

7

th Semester
Authors: Kampianakis Lefteris, Konstantinos Tountas

## PCB Tutorial

Intructor: Aggelos Bletsas
aggelos@telecom.tuc.gr

version 0.1.0

## Contents

1 What to expect from this manual | 3
2 Introduction | 4
3 Learning to design. | 5
4 Creating new components | 19
5 Layout Design Rules for RF Layout | 34

2

## 1 What to expect from this manual

Before reading this manual please read the TI design rules for RF PCB design.
This tutorial provides a basic introduction to the EAGLE PCB-Design Package. It covers the use of the EAGLE Schematic Editor, Layout Editor, and Autorouter. This guide will lead you through the program in the following order, starting with the Schematic Editor module and working through to board design and autorouting.
Having completed this tutorial you should be able to start working on a serious project. While creating your initial designs, however, you should frequently use the help function and the EAGLE Reference Manual to learn more about specific details.

3

## 2 Introduction

### 2.1 Before Getting Started

In this tutorial we will use the free edition of EAGLE. There are some restrictions but for learning purposes it’s ideal. Before we start designing we need to setup EAGLE and import the component libraries, useful keyboard shortcuts.
Things to do:
- Download Eagle itself. Versions are available for Windows, Linux, and Mac.
- Download the SparkFun Eagle Library. This is the collection of all the components SparkFun designs with and therefore components and footprints have already been tested. Unzip and put the SparkFun.lbr file into the Eagle\lbr directory.
- Download the SparkFun Eagle keyboard shortcuts. Place this file in the Eagle\scr directory. (Optional)
- Download the sfe-gerb274x.cam file needed for exporting the Eagle\cam directory.

When we are done with installing, we can start designing boards.

Note 1: For linux users, regular copy-paste won’t work. Use the mv command from the terminal.

Note 2: The SparkFun Eagle shortcut key script file has an .scr extension. This is a common virus infiltration method. If you choose to download the keyboard shortcuts, and you don’t trust us, rename the file to a .txt extension and view it in a text viewer. There’s nothing there but text and Eagle commands. Just be sure to rename the file to the .scr extension so that Eagle can use it.

4

3 Learning to design.

### 3.1 Design Process

A. Design the schematic on paper.
B. Simulate the circuit or prototype on a bred-board.
C. Test.
D. If the test is successful, we proceed to design using CAD software.

Note 1: Using CAD software is the last stage of of prototyping.

Note 2: Mistakes in the first stages of the design can be very expensive!

### 3.2 Cadsoft EAGLE

In this class we will use the EAGLE software. It’s free, easy to learn and use and is also used in the industry.
EAGLE software has 3 main functionalities:
- Schematic Design:
Using this functionality, we implement the circuit design we created in the earlier stages.
- Layout Design:
Using this functionality, we design the layout. (how the PCB looks)
- CAM files exporting:
Using this functionality, we create the files that we send to our fab house.

5

### 3.2.1 The Panel

A. Functions Toolbar.
B. Menu and useful functions.
C. Command Line.
D. Design panel.

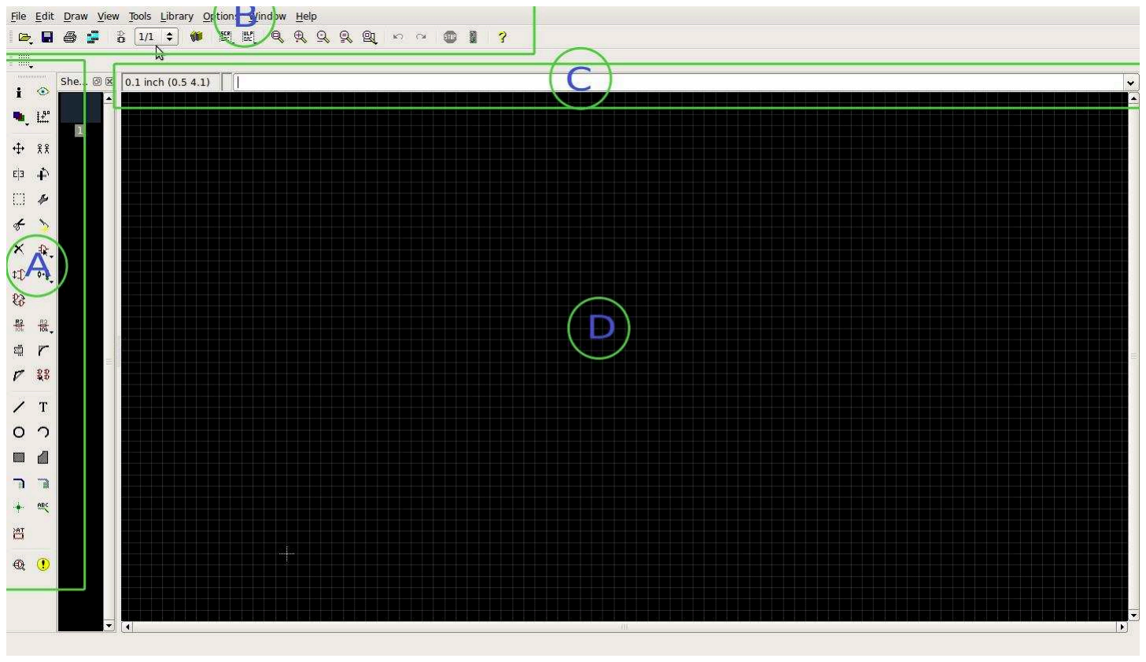
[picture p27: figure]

Σχήμα 1: The EAGLE schematic design window.

### 3.2.2 Starting to design

After the first stages of the designing process are completed and we have an idea of the circuit we want to design, we can start adding components to our schematic.
But before we start some things we need to know about the components:
- Components may exist (e.g. resistor, micro controller) or not (e.g GND, VCC)
- They have a different representation in the schematic and the layout
- Each component has package information, which describes the pads on the layout design.
- We can create our own components.

### 3.2.3 The Operational Amplifier

The circuit we are going to implement is an inverting operational amplifier. The gain of this amplifier is

A = −

Rf
R1

(1)

6

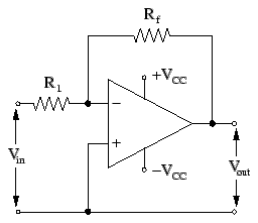
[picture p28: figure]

Σχήμα 2: Operational amplifier circuit.

And the circuit we are going to implement is the following:
For this implementation we want the gain to be A = −10, so the Rf = 1K and the R1 = 100.

### 3.2.4 Components List

All the components can be found in the Sparkfan library.

A. 2 x Resistor (smd package 1206)
B. 1 x 3 x 1 header (M03LOCK)
C. 2 x 1 x 1 header (M01PTH)
D. GND

7

### 3.2.5 Adding components to the design

In order to insert new components to the design we use the command ADD in the command line. A new window will open, where we search the component we need.

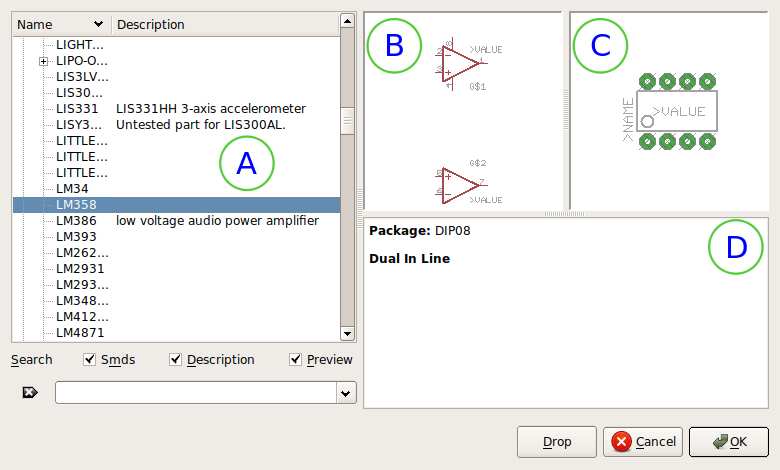
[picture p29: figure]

Σχήμα 3: The EAGLE ADD window.

After we find the component we need, let’s take a closer look on the ADD window.

A. Component List.
B. Preview of the component in the schematic design.
C. Preview of the component in the layout design.
D. Component description: usually contains package and component information.

We choose the component and we place it in the right position on the schematic design. In order to move the component around the schematic we use the command move and if we need to move many items we use the command group, then right click and move group. While moving a component we can right click in order to rotate it. Afterwards we do the same thing for all the other components.

Tip: We can either use the command line or the toolbar. The first one is faster, since we don’t need to type the whole command, just 2-3 letters are enough.

After we have all the components on the design, it should look like this:

8

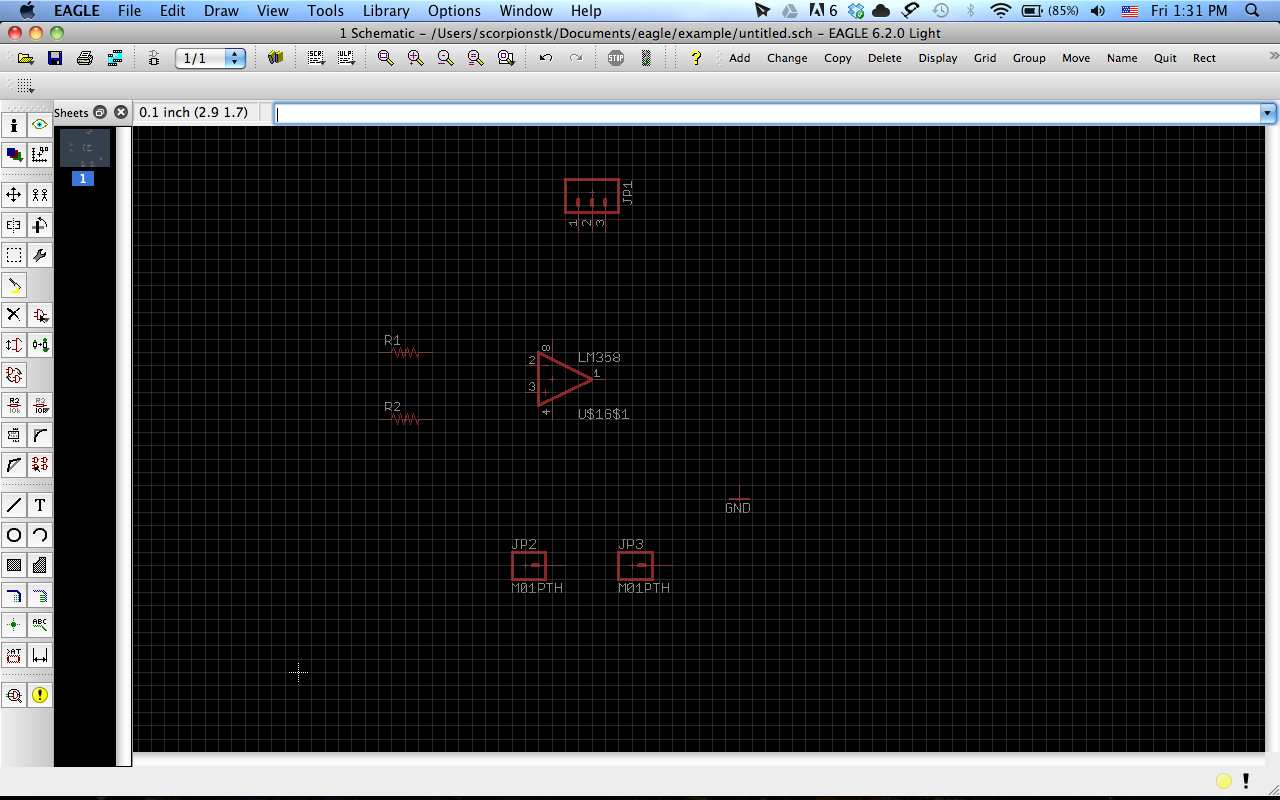
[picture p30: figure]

Σχήμα 4: The schematic with the unconnected components.

### 3.2.6 Renaming the components and changing values

Now we can rename the components so that we can understand the schematic better. Therefore we use the command name in order to change the name of the component and the command value in order to change the value of a component. e.g R2 → Rf , J1 → V in.

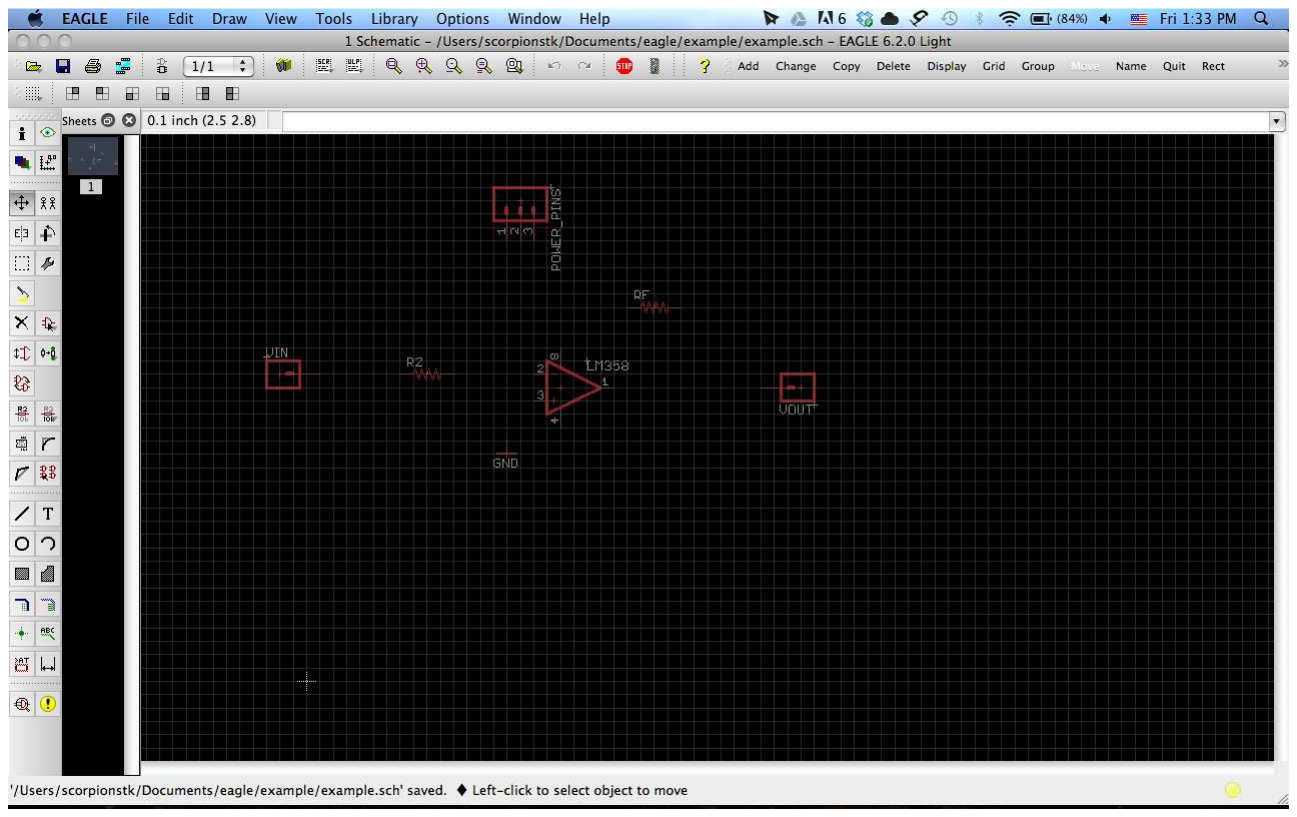
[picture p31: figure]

Σχήμα 5: The schematic after renaming the components.

### 3.2.7 Connecting the components

Now all we have to do is connect the components according to our circuit schematic. We do that using the wire command.

9

Tip: It’s good practice to use a junction when wires meet if we want them connected.

Tip: In order to check if a component is connect to a wire we use the move command. On the following photo we have connected everything but the 3 x 1 connector.

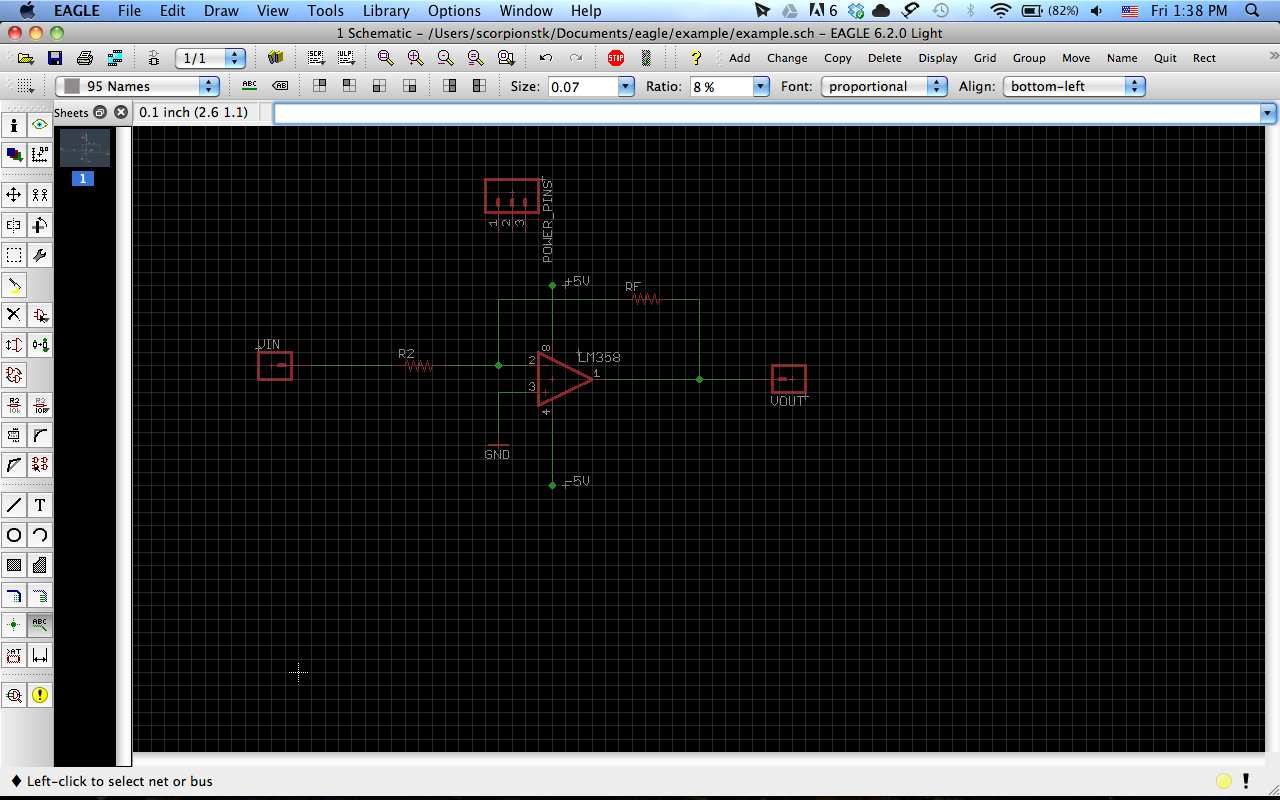
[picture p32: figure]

Σχήμα 6: The schematic with connected components.

Sometimes we need to connect components that are away from each other or in a position that is not easy for the wire to reach. In order to connect them we create an imaginary connection.

10

To create the imaginary connection:

A. We use the wire command to create a small wire from the pin we want to connect.

Σχήμα 7: Component before connecting the wire.

Σχήμα 8: Component after connecting the wire.

B. We put the junction at the end of the wire.

Σχήμα 9: Wire with junction.

C. We use the name command on the junction (or the wire) in order to name the net. e.g if we name it GND it will connect to the Ground.
D. We use the label command to label the junction in order to remember, where it’s connected.

11

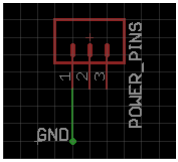
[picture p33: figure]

Σχήμα 10: Pin connected to GND.

We follow the aforementioned steps for each of the pins of the connector. The connector should look like this:

Σχήμα 11: All pins connected.

12

Tip: If the position of the name or the label of a component is not convenient, we can use the command smash in order to change their position.

Σχήμα 12: More beautiful and convenient way of design.

### 3.3 Connection checking

Next we must check if the components are connected correctly. In order to do it we use the command show on the wire we want to check. All the wires and components connected to the wire are highlighted. This way we can check for short circuits or unwanted connections.

### 3.3.1 Electrical Rules Check (ERC)

This is the last and most important step of the schematic design. We perform an ERC check to find all the errors and warnings. We need to check if we either need to change our design or approve them and continue to the layout design.
As you can see bellow we get an error about our negative power source. We can approve it because it’s not a problem in the design, we just don’t have a component for a negative power source so the ERC check thinks we are mistaken.

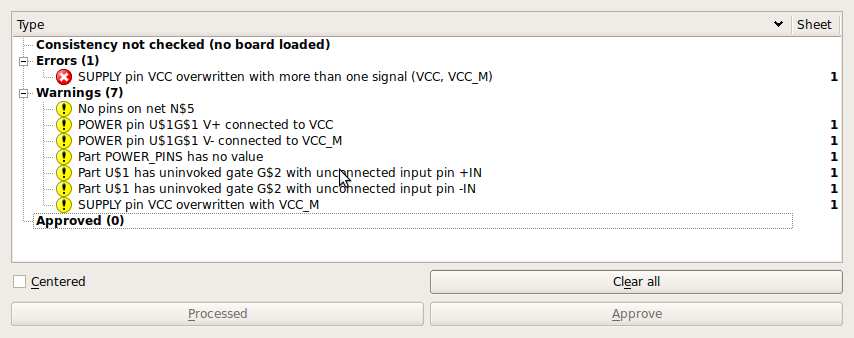
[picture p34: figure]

Σχήμα 13: ERC Check window.

13

### 3.4 Layout Design

Now we start the Layout Design, by clicking the board button on the Menu.

Σχήμα 14: Board button.

We click yes on the window that opens and a new window opens. This is the layout design window. Here the components are represented by their footprints, which are like the pads that are going to be on the actual PCB (on a different scale). The yellow lines are the connections between the pads of the components. Now we need to move the components on the board and figure out the dimensions of the white lines. The white lines are the shape that the final board will have.

Tip: We can create shapes other than rectangles, but the other shapes are more expensive.

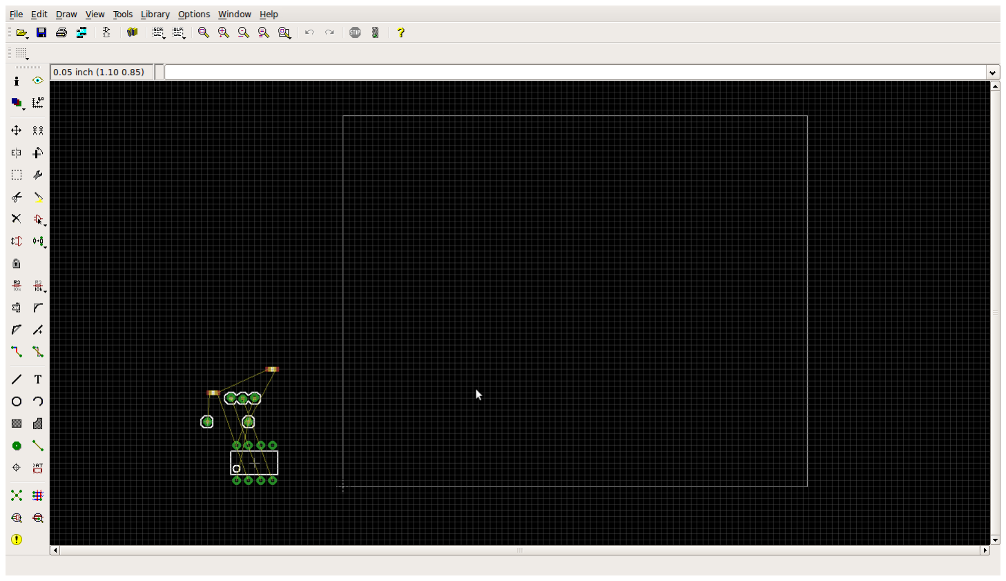
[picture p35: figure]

Σχήμα 15: The layout design window.

The layout design has many layers. In this free edition of EAGLE we can use only 2 layers, top and bottom, where we can place components.

### 3.4.1 Basic items used in layout design

- Pad: pieces of copper, where the components are placed (found in SMD components.
- Via: copper holes on the board, used to connect the top and the bottom layer.

14

- Drill Holes: holes on the board, used for supporting the components.
- Wires: wires that connect the pads and the vias. They are the physical connection between the components.

### 3.4.2 Rules Check (DRC)

Before designing the layout, we need to configure the DRC. We use the command DRC on the command window. The rules are given by the fab house and we can’t change them.
The DRC rules are essential for checking the design and for using the Auto-route tool.

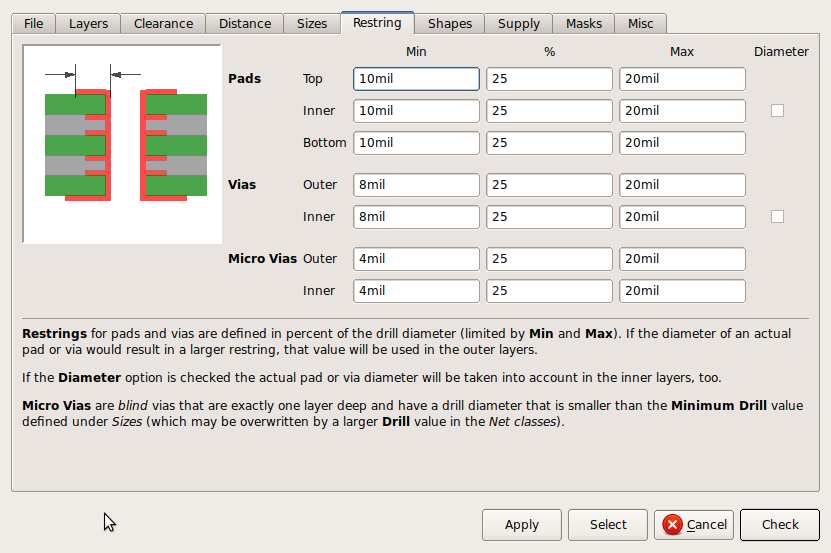
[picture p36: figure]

Σχήμα 16: DRC window.

15

### 3.4.3 Designing the layout

After the DRC is configured we can start placing the components on the board.
Tip: It’s good practice to design the board on paper first, in order to get a better idea of where to place the components before you design it with EAGLE.

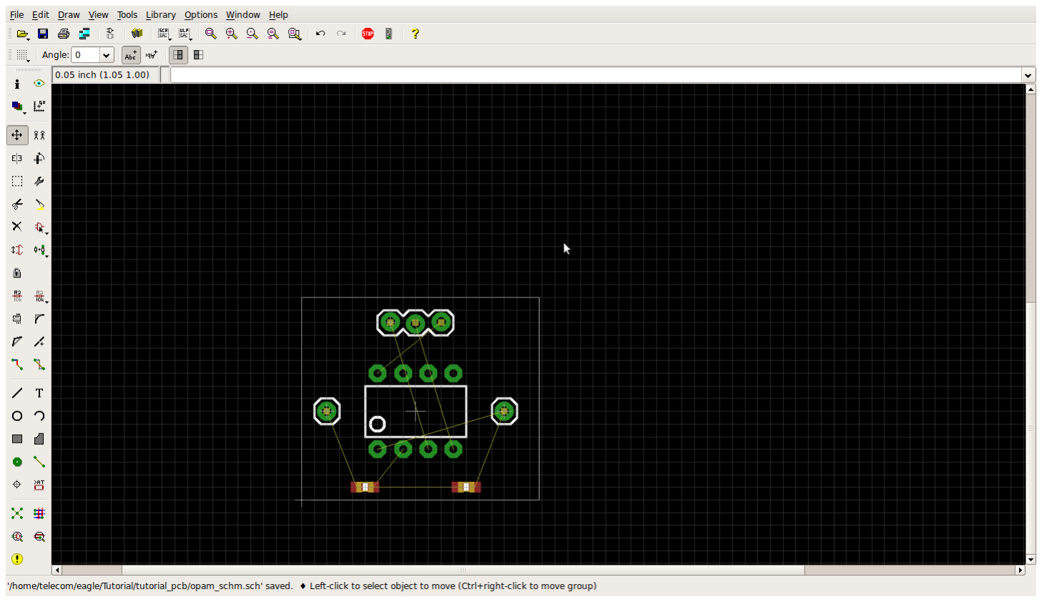
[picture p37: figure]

Σχήμα 17: Layout with all the footprints placed.

### 3.4.4 Routing: Connecting the pads

When the components are placed we need to connect the pads, as the yellow lines are connected. We have two choices:

- Auto-routing
- Manual-routing

Auto Routing: For Auto routing, we use the Auto Route button from the toolbar. Manual Routing: For manual routing, we use the command route. The following toolbar appears.

Layer | Style | Auto-route tools Edge smooting Drill select

Σχήμα 18: The Rsoute toolbar.

16

From this toolbar we choose the layer on which we want to design and the style of the wire. A very useful tool is the follow me router, with which EAGLE tries to follow the mouse while routing and find an optimal path to it, given the user constrains on the DRC.
Routing and layout design is a very difficult process that takes time to master it, so don’t get discouraged if you fail a couple of times.
Other useful tools used in layout design:
- rip: Deletes the routes from the layout. Be careful and don’t use delete for that.
- ratsnest: Calculates the shortest possible wires and polygons.
- group: groups components and wires.
- display: Choose layers. Very useful for checking the top-bottom layer.
- mark: Places a point reference on the layout in order to count distances.
- grid: changes the grid of the layout and the units of distance.

### 3.4.5 Designing the ground plane

The ground plane is a copper layer, placed under the top and bottom layer in order to minimize the noise generated by the circuit.
In order to create the ground plane we do the following:
A. Use the polygon command.
B. Design a polygon on both layers (top, bottom).
C. name each polygon GND.
D. use the command rat.

### 3.4.6 DRC again

After the design is over we have to do another DRC check. If everything is placed and connected correctly there should be no problems and we could continue to the gerber files export.

3.5 CAM files export.

Creating the gerber files:

- Download Cam Script from SparkFun.
- Open Cam processor.
- File → Open → Job.
- Select ”sfe-gerb274x.cam”.

17

- Go to Drill File tab.
- Change File from ”.TXT” to ”.DRD”.
- Process Job.
- Files created:
A. .GTS - Top Solder Mask
B. .GTP - Top Solder Paste
C. .GTO - Top Silkscreen
D. .GTL - Top Copper
E. .gpi - Apperture File
F. .GBS - Bottom Solder Mask
G. .GBL - Bottom Copper
H. .GBO - Bottom SilkScreen
I. .DRD - Drill File (2:4 Leading)
J. .dri - Drill Station Info File
- Copy the above only to a folder other than root (e.g Gerbers)
- Zip and and send the file to the fabhouse including a readme file with a list of corresponding files and explanation(see above)

Always check the CAM files:
View Exported Files:
- Download viewplot setup
- Install and run viewplot.
- File → Load files.
- Select all the output files except .DRD and .DRI.
- Click OK.
- Click Read apertures.
- Click OK.
- Load .DRD file.
- Click OK.
- Select 2 4 Number format and Leading zero suppression.

18

- Click OK.
- You should be seeing your pcb, check for errors

Always print a 1:1 version of your PCB and check if the components can be placed on the footprints.

## 4 Creating new components

Sometimes you can’t find the part you need in an existing library though, and it’s time to make your own. Making a new components in Cadsoft Eagle can be intimidating for new users, but this guide shows how we make our own Eagle components step by step. To start creating your own components, from the EAGLE control panel go to F ile → New → Library. This will open the component design window.

### 4.1 The part design process

A component is composed of 3 sections:

- Symbol - the thing you connect to other parts on the schematic
- Package - the footprint on the PCB that you attach the part to
- Device - a symbol and a package together. Symbol connections are assigned to package pins

### 4.2 Example: LM5022

Let’s take the LM5022 as an example, a simple 10 pin chip. The datasheet has the packaging dimensions we need to build the footprint.

Σχήμα 19: LM5022 diagram.

19

It’s very important to have the landing pattern and not just the pin dimensions. Some datasheets will only give the pin size, the landing pattern is larger and optimized to help the chip solder easily.

### 4.3 Making the symbol

Let’s start with the symbol. Symbols are what you connect to other parts in the schematic diagram. We will design this one as simple as a block with pins.

Σχήμα 20: The component Design toolbar.

Create a new symbol by clicking the symbol icon in the library editor.

Σχήμα 21: Edit symbol window.

A window will open and ask for a symbol name. Enter the chip name or part number and click OK, then click Yes when asked to create a new symbol.
In the chip’s datasheet we can find the pinout or connection diagram, this will be the basis for our symbol.
Start making the symbol by using the wire command in the 94Symbol layer as an outline, ICs are rectangular so we just make a simple box to represent the chip. Always put the symbol on its center (0 0) as this will be your anchor when moving in the schematic.
Place pins on the chip. Click the pin button, then click on the symbol to drop pins.

Hint: When placing the pins just leave the current settings for the grid (0.1inch), this makes the connection easier to snap when working with the device later.

20

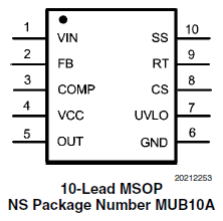
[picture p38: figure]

Σχήμα 22: LM5022 connection diagram.

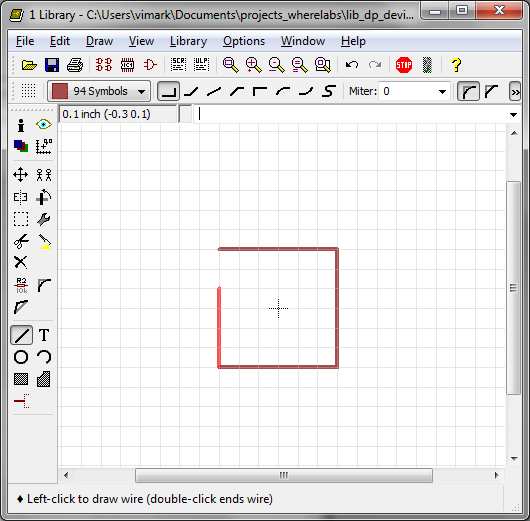
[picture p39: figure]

Σχήμα 23: Making the symbol step 1.

Name each pin by using the info command, and clicking on the pin. Name the pins according to the datasheet to make your life easier later. You can tweak other pin attributes in the info window too.
Add a space for the part designation on the 95Names layer. This is where the part number such as IC1, C3, or R2 will appear on the schematic.

21

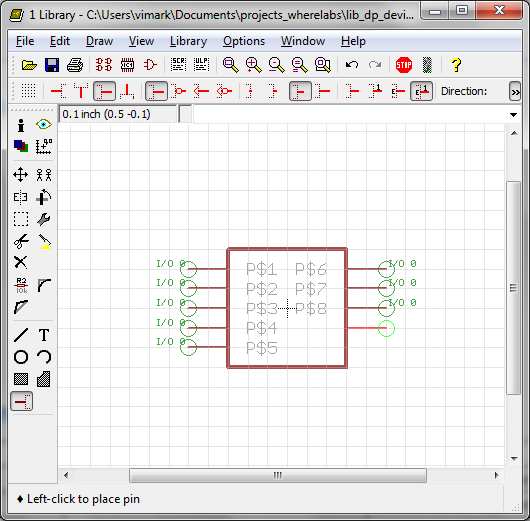
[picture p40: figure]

Σχήμα 24: Making the symbol step 2.


Σχήμα 25: Making the symbol step 3.

You can also place the value label for the part on the 96Values layer. We don’t usually assign a value because we usually change it in the schematic design phase.

### 4.4 Making the footprint

Footprints, sometimes called landing patterns, define where a chip attaches to a circuit board. The footprints will be the copper or silver shiny pads that you will solder parts on later. Eagle calls this a package.
To access the package editor click the package icon or the symbol icon and then choose Pac.
Name the package, this time by the package type which is MSOP-10 for this chip.

22


Σχήμα 26: Making the symbol step 4.


Σχήμα 27: Making the symbol step 5.

Σχήμα 28: Configuring the grid.

Time to configure the grid, by using the grid command. The datasheet gives the units in

23 inch and mm. We’ll go for the metric unit, but you could also use inches.

Σχήμα 29: Pads on the datasheet.

Check the datasheet for the dimensions of the recommended pin pads. We’ll use this to make the optimal pad in our footprint.
Here, the manufacturer recommends 0.3 x 1.02. This area will be slightly larger than the pin itself, and is optimized for the package type.

Important: It’s very important to have the landing pattern and not just the pin dimensions. Some datasheets will only give the pin size, the landing pattern is larger and optimized to help the chip solder easily.


Σχήμα 30: SMD toolbar.

This is a surface mount part, so we click SMD or use the SMD command to get the right pad. For through-hole parts click the round green via next to the SMD button.
Set the dimension of the pad to the values we pulled from the datasheet.

24

Σχήμα 31: SMD toolbar.

There are many ways to place the pad in the correct position. You can place it manually if the grid you set (View ¿ Grid) fits the pad pitch. Alternately you can calculate the correct pad coordinates, we’ll use this method.

What we’re going to do is calculate the location of the center of each pad using the values from the datasheet. This seems a little tedious, but we think it’s easier than messing with the grid values constantly.

The formula for the X axis is P x = (n − 1)Dpx where:

- n is the order of the pad from the center
- Dpx is the major pitch distance of each pad

For Pad 1 X (3rd pad from X center):

Pad1X=(3-1)0.5 will be 1. Since pad 1 is located on the 3rd quadrant its X value will be negative hence -1.

The formula for the Y axis is P y = Dpy/2 where:

- Dpy is the minor pitch distance of each pads

For Pad 1 Y

25

Pad1Y=4.8/2 will be 2.4. The lower pads are below the X axis, and should be negative. The Y location of Pad1 is Pad1Y=-2.4. On this chip pins 1-5 will have negative Y axis value (-2.4), and pins 6-10 will have a positive Y axis value (2.4).

- Pad2X=(2-1)0.5, and it’s still on the 3rd quadrant so the value is -0.5
- Pad2Y=(4.8)/2, still below X, -2.4
- Pad3X=(1-1)0.5, yields 0
- Pad3Y=(4.8/2), still below X, -2.4
- Pad4X=(2-1)0.5, now we’re on the fourth quadrant, which is on the positive side of X axis. This will be positive 0.5
- Pad4Y=(4.8/2). still at -2.4

Now we have: Pad1 at (-1 -2.4), Pad2 at (-0.5 -2.4), Pad3 at(0 -2.4), and Pad4(0.5 -2.4). Repeat for each pad. Remember that the Y values only need to be calculated once.

Coordinates: (-1 -2.4)(-.5 -2.4)(0 -2.4)(.5 -2.4)(1 -2.4)(1 2.4)(.5 2.4)(0 2.4)(-.5 2.4)(-1 2.4);

With these coordinates we can place the pads easily.

A. Click on the SMD pad button
B. Enter the coordinates into the command box at the top of the library editor as shown
C. Press enter. All pads are now in place


Σχήμα 32: Placing the pads. | Σχήμα 33: All pads placed.

26

Σχήμα 34: Creating the outline. | Σχήμα 35: Outline Done.

The order of the coordinates in the command box assigns numbering to the pads. Its not necessary to do it like that. You can always use the ’info’ command and edit the pad name or fix mistakes.
Now we’ll make the chip package and pin outline, again using the values from the datasheet. This is a 3x3 mm chip with 0.23x.95 sized pins.
Use the wire command to draw the outline on the top silk 21tPlace layer.
We used the package dimensions in the datasheet to calculate the coordinates of the chip’s 4 edges.

27

Σχήμα 36: Creating the outline. | Σχήμα 37: Outline Done.

It’s nice to see where the actual pins will be when you route the PCB. We’ll create a pin reference on the Document layer. We use the Document layer so the reference will not be included on the top silk or overlap the pin pads.

- Select the Rectangle command and set the layer to top Document 51tDocu layer
- Create a single pin centered on the part origin, this makes it easy to copy and snap onto our pads. We use a rectangle that is half of the width of the pad (0.23/2= 0.115).

28

Σχήμα 38: Placing the pins.

Use the Copy command to copy the first pin. Place a copy on each pad with its base touching the chip outline.


Σχήμα 39: Placing a circle.

When we’re building the board we need to know how to position parts. Mark pin 1 with a zero width circle on the top silk 21 tPlace layer. The zero width circle will fill up.

29


Σχήμα 40: Naming the chip. | Σχήμα 41: Naming the chip Done.

Finally put a ’name’ text near the chip, on the top silk name layer 25 tNames, and we’re done.

### 4.5 Making the Device

A device links the symbol and package and makes a complete part you can use in Eagle.

Σχήμα 42: The device button.

Create a new device by clicking the Device symbol.

30

Σχήμα 43: Importing the symbol. | Σχήμα 44: List of symbols.

Import the symbol by clicking the ’Add’ icon.
A window will pop-up with a list of symbols in the library. Pick the symbol that we made before and click OK.
Σχήμα 45: Importing the package. | Σχήμα 46: Package list.

Now import the package by clicking the ’New’ button.
Eagle highlights packages that will fit the symbol. Choose the package/footprint we created before.
In the variant name box enter the same name as the package. This can be used to make different sizes of the same device. Click OK.

31

Σχήμα 47: Package imported.

The footprint appears on the package list with an ’!’ icon showing that the symbol and the package are not linked or connected yet. Click the ’connect’ button to link both.

32

Σχήμα 48: Unpaired pins.


Σχήμα 49: Each pin is connected to only one pad.

After clicking the connect button, another window will appear showing unpaired pins. Match each symbol pin with the corresponding pad and click connect. Each pin should only connect to one pad.


Σχήμα 50: Using the Prefix button.

Finally, click the Prefix button and specify a prefix for this chip. Eagle will automatically increment this when you make your schematic, e.g IC1, IC2, IC3. It will also identify this part in your bill of materials.
Save the library and you can try your newly created part.

33

## 5 Layout Design Rules for RF Layout

- Keep via inductance as low as possible. Usually means larger holes or multiple parallel holes)
- Keep top ground continuous as possible. Similarly for bottom ground.
- Make the number of return paths equal for both digital and RF

– Current flow is always through the path with least impedance. Therefore digital signals should not find a lower impedance path through the RF sections.

- Compact RF paths are better, but observe good RF isolation between pads and or traces.
- Keep copper layer continuous for grounds. Keep connections to supply layers short
- Use vias to move the PCB self resonance higher than signal frequencies
- Keep trace and components spacing no less than 12 mils.
- Keep via holes large at least 14.5 mils
- Separate high speed signals (e.g. clock signals) from low speed signals, digital from analog. Placement is critical to keep return paths free of mixed signals.
- Route digital signals traces so antenna field lines are not in parallel to magnetic fields lines.
- Keep traces length runs under a 1/4 wavelength when possible.
- Avoid discontinuities in ground layers
- Don’t use sharp right angle bends

34

- Do not have vias between bypass caps

35

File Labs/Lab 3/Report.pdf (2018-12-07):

# Ανάλυση και Σχεδίαση Τηλεπικοινωνιακών Διατάξεων

### Αναφορά Εργαστηρίου 3 Φωτάκης Τζανής - 2014030054

Σε συνεργασία με Πίσκοπο Διονύση

# Ερώτημα 1

Σύμφωνα με το manual του cc2500, μια μετάδοση πακέτου ξεκιναει με το preamble, το οποιο αποτελειται απο 8*n bits, ακολουθούμενο από το sync μεγεθους 2 bytes, αν υπαρχει πληροφορια στην TX_FIFO. Στην συνέχεια, μεταδίδεται το περιεχόμενο της TX_FIFO. Τα πρωτα 2 bytes της μεταδοσης, αποτελουν το length του συνολικου πακετου και την διευθυνση του παραληπτη, ενα byte για το καθε πεδιο, ενω τα υπολοιπα bytes ανηκουν στο payload και στο CRC. Για την ρυθμιση του μεγεθους του πακετου αποστολης θα πρεπει να γινει η καταλληλη ρυθμιση του καταχωρητη PKTLEN (ελάχιστο μέγεθος payload 1 byte, μεγιστο μεγεθος πακετου= 256 bytes). Για τον καθορισμο του μεγεθους του preamble οριζουμε καταλληλα τα bit 4:6 του καταχωρητη MDMCFG1. Για τον καθορισμο του sync mode, αρκει να ορίσουμε τα bit 0:2 του καταχωρητη MDMCFG2. Για να την τιμη του sync word αρκει να ορίσουμε καταλληλα τους καταχωρητες SYNC1 & SYNC0.

# Ερώτημα 2

- PKTLEN = 0xFF: Μήκος πακέτου 256 bytes
- MDMCFG1 = 0x22: MDMCFG1[6:4] = 010 ⇒ 4 preamble bytes
- MDMCFG2 = 0x73: MDMCFG2[2:0] = 011 ⇒ 30/32 sync word bits detected
- SYNC1 & SYNC0 διατηρούν τις default τιμές τους

# Ερώτημα 3

Σύμφωνα με το RF Studio οι ρυθμίσεις (διαφορές σε σχέση με τις ρυθμίσεις του προηγούμενου ερωτήματος) που πρέπει να γίνουν στο ραδιόφωνο για να λειτουργεί στην μέγιστη ισχύ εκπομπής και ταχύτητα κάτω από 4 kbps είναι οι παρακάτω:
- FSCTRL1 = 0χ08
- MDMCFG4 = 0χ87
- MDMCFG3 = 0χ43
- MDMCFG2 = 0χ03
- DEVIATN = 0χ44
- FOCCFG = 0χ16
- paTable = 0xFF
Με τις παραπάνω ρυθμίσεις μετρήθηκε πειραματικά η απόσταση που απαιτείται για να αρχίσουν να χάνονται πακέτα. Ο ένας μικροελεγκτής σε ρύθμιση πομπού τοποθετήθηκε μέσα στο εργαστήριο και ο μικροελεγκτής σε ρύθμιση δέκτη τοποθετήθηκε στο εσωτερικό του διαδρόμου της κοντινότερης πτέρυγας του κτηρίου επιστημών. Έτσι, παρατηρήθηκε ότι το σήμα ξεκίνησε να χάνεται στα 40 βήματα, δηλαδή περίπου στα 20 μέτρα. Σημαντικό να αναφερθεί είναι ότι για να καταφέρουν να επικοινωνήσουν ο πομπός και ο δέκτης πρέπει να έχουν πανομοιότυπη ρύθμιση, πράγμα που συμβαίνει σε όλα τα ερωτήματα. Ο σχετικός κώδικας για τον δέκτη βρίσκεται στο αρχείο “Q3MaxPowerRX.c” ενώ για τον πομπό στο αρχείο “Q3MaxPowerΤX.c”.

# Ερώτημα 4

Επαναλαμβάνοντας το παραπάνω ερώτημα με την διαφορά ότι πρέπει να χρησιμοποιηθεί η μέγιστη ταχύτητα μετάδοσης προέκυψαν οι παρακάτω απαιτούμενες ρυθμίσεις (διαφορές σε σχέση με τις ρυθμίσεις του προηγούμενου ερωτήματος):
- FSCTRL1 = 0x0c
- MDMCFG4 = 0x0e
- MDMCFG3 = 0x3b
- MDMCFG2 = 0x73
- MDMCFG1 = 0x42
- DEVIATN = 0x00
- FOCCFG = 0x1d
- AGCCTRL1 = 0x40
- FSCAL0 = 0x19
Με τις παραπάνω ρυθμίσεις μετρήθηκε πειραματικά η απόσταση που απαιτείται για να αρχίσουν να χάνονται πακέτα. Ο ένας μικροελεγκτής σε ρύθμιση πομπού τοποθετήθηκε μέσα στο εργαστήριο και ο μικροελεγκτής σε ρύθμιση δέκτη τοποθετήθηκε στο εσωτερικό του διαδρόμου της κοντινότερης πτέρυγας του κτηρίου επιστημών. Έτσι, παρατηρήθηκε ότι το σήμα ξεκίνησε να χάνεται στα 20 βήματα, δηλαδή περίπου στα 10 μέτρα. Ο σχετικός κώδικας για τον δέκτη βρίσκεται στο αρχείο “Q4MaxPowerAndSpeedRX.c” ενώ για τον πομπό στο αρχείο “Q4MaxPowerAndSpeedΤX.c”.

# Ερώτημα 5

Για την επίτευξη του συγκεκριμένου ερωτήματος υλοποιήθηκε κώδικας με τις αρχικές ρυθμίσεις ραδιοφώνου (τις ρυθμίσεις που υπήρχαν στον δοσμένο κώδικα), ο οποίος με το πάτημα του κουμπιού SW2 που είναι συνδεδεμένο στο P2.0 ο μικροελεγκτής μεταβαίνει από την ρύθμιση πομπού σε ρύθμιση δέκτη και αντιστρόφως. Για να μην υπάρχει πρόβλημα κατά την μετάβαση καταστάσεων εκ αιτίας ότι η μέθοδος λήψης είναι blocking (επιστρέφει μόνο αν έχει γίνει λήψη ενός πακέτου) πρέπει πρώτα να μεταβεί ο δέκτης σε πομπό και μετά ο πομπός σε δέκτη. Ο σχετικός κώδικας βρίσκεται στο αρχείο “Q5SwitchingModes.c”.

# Ερώτημα 6

Για την επίτευξη του συγκεκριμένου ερωτήματος υλοποιήθηκε κώδικας με τις αρχικές ρυθμίσεις ραδιοφώνου (τις ρυθμίσεις που υπήρχαν στον δοσμένο κώδικα), ο οποίος ξεκινάει τους μικροελεγκτές σε λειτουργία πομπού, αποστέλλεται ένα πακέτο και αμέσως μεταβαίνει σε λειτουργία δέκτη όπου και περιμένει μέχρι να λάβει πακέτο από τον πομπό. Μόλις γίνει λήψη πακέτου ο δέκτης περιμένει λίγο χρόνο ώστε να προλάβει ο μικροελεγκτής που έχει τον ρόλο του πομπού να μεταβεί σε λειτουργία δέκτη και αμέσως μετά αλλάζει ο πρώτος σε λειτουργία πομπού όπου και επαναλαμβάνεται η διαδικασία. Όταν ο μικροελεγκτής είναι σε λειτουργία πομπού το LED είναι σβηστό ενώ είναι αναμμένο σε λειτουργία δέκτη. Ο σχετικός κώδικας φορτώνεται και στους δύο μικροελεγκτές και βρίσκεται στο αρχείο “Q6PingPong.c”.

# Ερώτημα 7

Για την επίτευξη του συγκεκριμένου ερωτήματος υλοποιήθηκε κώδικας με τις αρχικές ρυθμίσεις ραδιοφώνου (τις ρυθμίσεις που υπήρχαν στον δοσμένο κώδικα), ο οποίος χρησιμοποιώντας την σειριακή θύρα και την δυνατότητα UART του μικροελεγκτή εκτυπώνει μία εκτίμηση του RSSI που βλέπει ο δέκτης. Η μέτρηση RSSI δίνεται από το πρώτο Byte του status που προέρχεται μέσα από τα τελευταία 2 Byte της RX_FIFO. Έτσι, δίδοντας την τιμή αυτή σε μία global μεταβλητή με όνομα RSSI_Measurement είναι εφικτή η εκτύπωσή της μέσω του UART στο τερματικό (Hercules). O σχετικός κώδικας βρίσκεται στο αρχείο “Q7RSSI.c” και φορτώνεται μόνο στον ένα μικροελεγκτή (στο DevKit) ενώ στον άλλο φορτώνεται ο δοσμένος κώδικας πομπού.

# Ερώτημα 8

Για την επίτευξη του συγκεκριμένου ερωτήματος υλοποιήθηκε κώδικας με τις αρχικές ρυθμίσεις ραδιοφώνου (τις ρυθμίσεις που υπήρχαν στον δοσμένο κώδικα), ο οποίος κατά την λειτουργία πομπού στέλνει συνεχώς πακέτα, το είδος των οποίων εξαρτάται με την κατάσταση του κουμπιού SW2 που είναι συνδεδεμένο στην θύρα P2.0. Όταν το κουμπί είναι πατημένο αποστέλλεται το πακέτο “onPacket” το οποίο περιέχει μία σειρά από άσσους ενώ όταν δεν είναι πατημένο αποστέλλεται το πακέτο “offPacket” το οποία περιέχει μία σειρά από μηδενικά. Αντίστοιχα, ο δέκτης όποτε δέχεται ένα πακέτο ελέγχει τα περιεχόμενά του ώστε να αποφασίσει αν του αποστέλλεται το onPacket ή το offPacket και ανάλογα το πακέτο ανάβει ή σβήνει το LED. Ο σχετικός κώδικας βρίσκεται στα αρχεία “Q8MorseTX.c” και “Q8MorseRX.c”.

# Ερώτημα 9

Το συγκεκριμένο ερώτημα είναι πανομοιότυπο με το ερώτημα 6 με την διαφορά στο ότι τα κανάλια διαφέρουν ανάλογα την λειτουργία πομπού ή δέκτη. Έτσι, κατά την αλλαγή λειτουργίας γίνεται και μία εγγραφή στον CHANN register του ραδιοφώνου με σκοπό την κατάλληλη αλλαγή του καναλιού στο οποίο αποστέλλει/λαμβάνει. Ο σχετικός κώδικας βρίσκεται στο αρχείο “Q9PingPongAll.c”.

# Σχόλια κώδικα

Για την καλύτερη διαχείριση και readability του κώδικα του εργαστηρίου δημιουργήθηκε το αρχείο radio.h το οποίο περιλαμβάνει όλες τις συναρτήσεις για την διαχείριση του ραδιοφώνου και την ρύθμιση των μικροελεγκτών και ραδιοφώνου. Επίσης για κάθε ερώτημα δημιουργήθηκαν αρχεία τα οποία κάνουν include το αρχείο radio.h και περιλαμβάνουν την δήλωση του struct ρύθμισης του ραδιοφώνου και την συνολική λειτουργικότητα του μικροελεγκτή. Όλες οι υλοποιήσεις των ερωτημάτων βρίσκονται μέσα στον φάκελο src στα αρχεία που αναφέρονται παραπάνω για κάθε ερώτημα.

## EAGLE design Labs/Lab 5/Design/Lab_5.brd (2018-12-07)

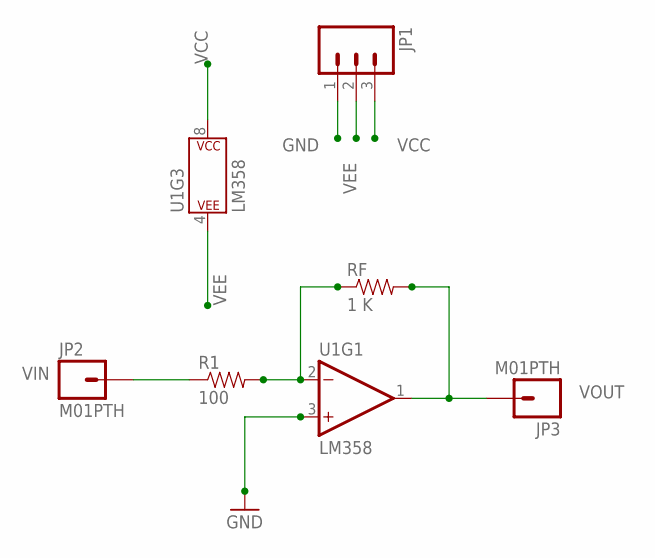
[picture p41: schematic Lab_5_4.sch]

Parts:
JP1: M03LOCK; 1X03_LOCK
JP2, JP3: M01PTH; 1X01
R1: 100; 1206
RF: 1 K; 1206
U1: LM358; DIP08-KIT

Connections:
FDBCK: R1.2, RF.1, U1.2 (-IN)
GND: JP1.1, U1.3 (+IN)
VCC: JP1.3, U1.8 (P$V+)
VEE: JP1.2, U1.4 (P$V-)
VIN: JP2.1, R1.1
VOUT: JP3.1, RF.2, U1.1 (OUT)

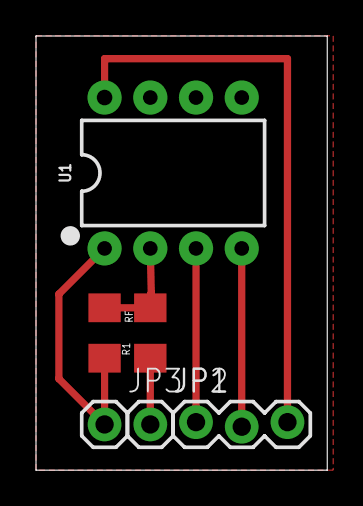
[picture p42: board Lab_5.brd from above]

Board: 2 copper layers, 16.2 x 24.1 mm, 6 parts (0 on the bottom side), 6 nets.

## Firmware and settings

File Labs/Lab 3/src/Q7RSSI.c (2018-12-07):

#include "radio.h"
#include <stdio.h>


#define BAUDRATE        9600           // Baud rate of UART in bps

#define RSSI_OFFSET     72

//-------------------------------------------------------------------------------------------------------
//  Radio settings
//-------------------------------------------------------------------------------------------------------
// Chipcon
// Product = CC2500
// Chip version = E   (VERSION = 0x03)
// Crystal accuracy = 10 ppm
// X-tal frequency = 26 MHz
// RF output power = 0 dBm
// RX filterbandwidth = 541.666667 kHz
// Phase = 1
// Datarate = 249.938965 kBaud
// Modulation = (7) MSK
// Manchester enable = (0) Manchester disabled
// RF Frequency = 2432.999908 MHz
// Channel spacing = 199.951172 kHz
// Channel number = 6
// Optimization = Sensitivity
// Sync mode = (3) 30/32 sync word bits detected
// Format of RX/TX data = (0) Normal mode, use FIFOs for RX and TX
// CRC operation = (1) CRC calculation in TX and CRC check in RX enabled
// Forward Error Correction = (0) FEC disabled
// Length configuration = (1) Variable length packets, packet length configured by the first received byte after sync word.
// Packetlength = 255
// Preamble count = (2)  4 bytes
// Append status = 1
// Address check = (0) No address check
// FIFO autoflush = 0
// Device address = 0
// GDO0 signal selection = ( 6) Asserts when sync word has been sent / received, and de-asserts at the end of the packet
// GDO2 signal selection = (41) CHIP_RDY

RF_SETTINGS code rfSettings = {
    0x0A,   // FSCTRL1      Frequency synthesizer control.
    0x00,   // FSCTRL0      Frequency synthesizer control.
    0x5D,   // FREQ2        Frequency control word, high byte.
    0x93,   // FREQ1        Frequency control word, middle byte.
    0xB1,   // FREQ0        Frequency control word, low byte.
    0x2D,   // MDMCFG4      Modem configuration.
    0x3B,   // MDMCFG3      Modem configuration.
    0x73,   // MDMCFG2      Modem configuration.
    0x22,   // MDMCFG1      Modem configuration.
    0xF8,   // MDMCFG0      Modem configuration.
    0x06,   // CHANNR       Channel number.
    0x01,   // DEVIATN      Modem deviation setting (when FSK modulation is enabled).
    0xB6,   // FREND1       Front end RX configuration.
    0x10,   // FREND0       Front end TX configuration.
    0x18,   // MCSM0        Main Radio Control State Machine configuration.
    0x1D,   // FOCCFG       Frequency Offset Compensation Configuration.
    0x1C,   // BSCFG        Bit synchronization Configuration.
    0xC7,   // AGCCTRL2     AGC control.
    0x00,   // AGCCTRL1     AGC control.
    0xB0,   // AGCCTRL0     AGC control.
    0xEA,   // FSCAL3       Frequency synthesizer calibration.
    0x0A,   // FSCAL2       Frequency synthesizer calibration.
    0x00,   // FSCAL1       Frequency synthesizer calibration.
    0x11,   // FSCAL0       Frequency synthesizer calibration.
    0x59,   // FSTEST       Frequency synthesizer calibration.
    0x88,   // TEST2        Various test settings.
    0x31,   // TEST1        Various test settings.
    0x0B,   // TEST0        Various test settings.
    0x07,   // FIFOTHR      RXFIFO and TXFIFO thresholds.
    0x29,   // IOCFG2       GDO2 output pin configuration.
    0x06,   // IOCFG0D      GDO0 output pin configuration.
    0x04,   // PKTCTRL1     Packet automation control.
    0x05,   // PKTCTRL0     Packet automation control.
    0x00,   // ADDR         Device address.
    0xFF    // PKTLEN       Packet length.
};

BYTE code paTable = 0xFE;   // PATABLE (0 dBm output power)


void UART0_Init (void){
	P0MDOUT |= 0x10;                    // enable UTX as push-pull output
	XBR0    |= 0x01;                     // Enable UART on P0.4(TX) and P0.5(RX)
	XBR1    |= 0x40;                     // Enable crossbar and weak pull-ups

	SCON0 = 0x10;                       // SCON0: 8-bit variable bit rate
										//        level of STOP bit is ignored
										//        RX enabled
										//        ninth bits are zeros
										//        clear RI0 and TI0 bits
	if (SYSCLK/BAUDRATE/2/256 < 1) {
		TH1 = -(SYSCLK/BAUDRATE/2);
		CKCON &= ~0x0B;                  // T1M = 1; SCA1:0 = xx
		CKCON |=  0x08;
	} else if (SYSCLK/BAUDRATE/2/256 < 4) {
		TH1 = -(SYSCLK/BAUDRATE/2/4);
		CKCON &= ~0x0B;                  // T1M = 0; SCA1:0 = 01
		CKCON |=  0x01;
	} else if (SYSCLK/BAUDRATE/2/256 < 12) {
		TH1 = -(SYSCLK/BAUDRATE/2/12);
		CKCON &= ~0x0B;                  // T1M = 0; SCA1:0 = 00
	} else {
		TH1 = -(SYSCLK/BAUDRATE/2/48);
		CKCON &= ~0x0B;                  // T1M = 0; SCA1:0 = 10
		CKCON |=  0x02;
	}

	TL1 = TH1;                          // init Timer1
	TMOD &= ~0xf0;                      // TMOD: timer 1 in 8-bit autoreload
	TMOD |=  0x20;
	TR1 = 1;                            // START Timer1
	TI0 = 1;                            // Indicate TX0 ready
}


//-------------------------------------------------------------------------------------------------------
//  Setup
//-------------------------------------------------------------------------------------------------------
void setup(void) {
    // PCA0MD &= ~0x40;         // Disable watchdog timer
    // SYSCLK_Init ();          // Initialize system clock to 24.5MHz
    CLOCK_INIT();               // Initialize clock
    PORT_Init ();               // Initialize crossbar and GPIO
    SPI_INIT(SCLK_6_MHZ);       // Initialize SPI

    UART0_Init();

    waitRadioForResponce();     // you need to wait ~41 usecs, before CC2500 responds
    resetRadio();

    halRfWriteRfSettings(&rfSettings);
    halSpiWriteReg(CCxxx0_PATABLE, paTable);

    EA = 1;                     // Enable global interrupts
}


//-------------------------------------------------------------------------------------------------------
//  Global Variables
//-------------------------------------------------------------------------------------------------------
BYTE  xdata txBuffer[] = {20, 0, 1, 2, 3, 4, 5, 6, 7, 8, 9, 10, 11, 12, 13, 14, 15, 16, 17, 18, 19};
BYTE  xdata rxBuffer[61];    // Length byte  + 2 status bytes are not stored in this buffer
UINT8 xdata mode = MODE_NOT_SET;

UINT32 packetsReceived = 0;
UINT32 packetsSent = 0;
UINT8 length;
BYTE mytestbyte;


float RSSI_convert(BYTE RSSI_read) {
	int rssi_dec = (int) RSSI_read;
	if(rssi_dec >= 128)
        return (rssi_dec-256)/2 - RSSI_OFFSET;
	else
		return rssi_dec/2- RSSI_OFFSET;
}


void txMode(void){
    //TX mode
    halRfSendPacket(txBuffer, sizeof(txBuffer));
    //intToAscii(++packetsSent);
    //endof TX mode

    halWait(30000);
    halWait(30000);
    LED = 0;
    halWait(30000);
    halWait(30000);
}


void rxMode(void){
    //RX mode
    length = sizeof(rxBuffer);
    if (halRfReceivePacket(rxBuffer, &length)) {
        intToAscii(++packetsReceived);
        LED = ~LED;

        mytestbyte = rxBuffer[0];
        mytestbyte = rxBuffer[1];
        mytestbyte = rxBuffer[2];
        mytestbyte = rxBuffer[3];
        mytestbyte = rxBuffer[4];
        mytestbyte = rxBuffer[5];
        mytestbyte = rxBuffer[6];
        mytestbyte = rxBuffer[7];
        mytestbyte = rxBuffer[8];
        mytestbyte = rxBuffer[9];
    }
}


//-------------------------------------------------------------------------------------------------------
//  Loop
//-------------------------------------------------------------------------------------------------------
void loop(void) {
   	rxMode();
    printf ("\nRSSI=%f",RSSI_convert(RSSI_Measurement));
}


//-------------------------------------------------------------------------------------------------------
// MAIN Routine
//-------------------------------------------------------------------------------------------------------
void main (void) {
    setup();
    while (1) loop();
}

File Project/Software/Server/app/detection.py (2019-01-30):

from threading import Thread
from queue import Queue
import time

import serial
import json

plotting = False

if plotting:
    import pylab

import random
import subprocess
import numpy


ser = serial.Serial('/dev/ttyUSB0', 9600)
TRAINING = False

if TRAINING:
	from pynput import keyboard

if plotting:
    xq = Queue()
    vq = Queue()

Data = [True]*5
Keyboard = [False]*5
Done = False


def playdatshit():
    subprocess.call(["ffplay", "-nodisp", "-autoexit", "-loglevel", "panic", "./app/fire.mp3"])

def fetch_uart():
    global Data
    x = []
    vals = [[], [], [], [], []]
    fft_vals = [[], [], [], [], []]

    data = [False]*5
    plot_mem = 120
    fft_mem = 16
    flag = False
    while True:
        ser_inp = ser.readline()
        t = time.time()
        x.append(t)
        if len(x) > plot_mem:
            x.pop(0)
            for i in range(5):
                vals[i].pop(0)
        if plotting:
            xq.put(x)
            vq.put(vals)
        values = [int(el) for el in ser_inp.split()]
        for i in range(5):
            if values[i] > 1023:
                values[i] = 1023
            elif values[i] < 0:
                values[i] = 0
        for i in range(5):
            vals[i].append(values[i])
            if len(vals[i]) < fft_mem:
                fft_vals[i] = vals[i]
            else:
                fft_vals[i] = vals[i][len(vals[i])-fft_mem:]
        data = fft_detection(fft_vals)
        #if flag:
        #    t4 = Thread(target=playdatshit)
        #    t4.start()
        Data = data
        print(values)
        print(data)
        logger = open("log.data", "a")
        logger.write(json.dumps({"ts": t, "val": values, "smk": data})+"\n")
        logger.close()

def fetch_uart_training():
    global Keyboard
    global Done
    x = []
    vals = [[], [], [], [], []]

    data = [False]*5
    new_data = [False]*5
    plot_mem = 120
    flag = False
    while not Done:
        ser_inp = ser.readline()
        t = time.time()
        x.append(t)
        if len(x) > plot_mem:
            x.pop(0)
            for i in range(5):
                vals[i].pop(0)
        if plotting:
            xq.put(x)
            vq.put(vals)
        values = [int(el) for el in ser_inp.split()]
        for i in range(5):
            if values[i] > 1023:
                values[i] = 1023
            elif values[i] < 0:
                values[i] = 0
        for i in range(5):
            vals[i].append(values[i])
        print(values)
        print(Keyboard)
        logger = open("log.data", "a")
        logger.write(json.dumps({"ts": t, "val": values, "smk": Keyboard})+"\n")
        logger.close()

def plotter():
    global Done
    while not Done:
        x = xq.get()
        vals = vq.get()
        pylab.clf()
        pylab.plot(x, vals[0], x, vals[1], x, vals[2], x, vals[3], x, vals[4])
        pylab.legend(["1", "2", "3", "4", "5"])
        pylab.pause(0.0001)
    pylab.close()

def fft_detection(vals):
    N = len(vals[0])
    FW = N/4 - 1
    data = []
    for i in range(5):
        #print(vals[i])
        fft_t = (numpy.fft.fftshift(numpy.fft.fft(vals[i])))
        fft_t = sum(abs(fft_t[int(N/2+1):]))/N/FW
        print(fft_t)
        if fft_t > 1:
            data.append(True)
        else:
            data.append(False)
    #print(data)
    return data


def randomshit():
    global Data
    while(True):
        Data = [random.random()<0.05 for _ in range(5)]
        flag = False
        for i in range(6):
            if Data[i]:
                flag = True
        if flag:
            t4 = Thread(target=playdatshit)
            t4.start()
        time.sleep(0.5)

def getData():
    global Data
    return {'tables': Data}

def on_press(key):
    global Keyboard
    try:
        if key.char in ["1", "2", "3", "4", "5"]:
            Keyboard[int(key.char)-1] = True
    except:
        pass

def on_release(key):
    global Keyboard
    global Done
    try:
        if key.char in ["1", "2", "3", "4", "5"]:
            Keyboard[int(key.char)-1] = False
    except:
        if key==keyboard.Key.esc:
            Done = True
            return False

if __name__=="__main__":
    cmd = fetch_uart_training

    t1 = Thread(target=cmd)
    t1.start()

    if plotting:
        t2 = Thread(target=plotter)
        t2.start()

    if TRAINING:
        with keyboard.Listener(on_press=on_press, on_release=on_release) as listener:
            listener.join()
            t1.join()
            t2.join()
    #t3 = Thread(target=randomshit)
    #t3.start()
else:
    cmd = fetch_uart

    t1 = Thread(target=cmd)
    t1.start()

    if plotting:
        t2 = Thread(target=plotter)
        t2.start()

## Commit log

2018-12-17 Changed master printf message & led - Changed slave led & send data - Updated detection.py
2018-12-18 Updated detection.py - Cleaned up slave.c - First implementation of PWM on CEX0 on master (On/Off Using UART Pending)
2018-12-20 Implemented UART0 Interrupt on master
2019-01-17 Switched rfSettings to Max Gain and lowest bit rate
2019-02-12 Inserted images on README.md

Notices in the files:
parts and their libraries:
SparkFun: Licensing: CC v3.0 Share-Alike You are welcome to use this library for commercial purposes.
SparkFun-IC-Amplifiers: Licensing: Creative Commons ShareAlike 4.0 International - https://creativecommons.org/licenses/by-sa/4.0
